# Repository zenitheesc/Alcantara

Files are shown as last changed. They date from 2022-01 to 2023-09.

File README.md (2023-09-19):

<h1 align="center" style="color:white; background-color:black">Alcantara</h1>
<h4 align="center"> Mobile Ground Station for stratospheric probe monitoring and rescue</h4>

<p align="center">
	<a href="http://zenith.eesc.usp.br/">
    
    </a>
    <a href="https://eesc.usp.br/">
    
    </a>
    <a href="https://github.com/zenitheesc/Alcantara_v.1.0/blob/experimental_realocate_components/LICENSE">
    
    </a>
    <a href="https://github.com/zenitheesc/Alcantara_v.1.0/issues">
    
    </a>
    <a href="https://github.com/zenitheesc/Alcantara_v.1.0/commits/experimental_realocate_components">
    
    </a>
    <a href="https://github.com/zenitheesc/Alcantara_v.1.0/graphs/contributors">
    
    </a>
    <a href="https://github.com/zenitheesc/Alcantara_v.1.0/commits/experimental_realocate_components">
    
    </a>
    <a href="https://github.com/zenitheesc/Alcantara_v.1.0/issues">
    
    </a>
    <a href="https://github.com/zenitheesc/Alcantara_v.1.0/pulls">
    
    </a>
</p>

<p align="center">
    <a href="#environment-and-tools">Environment and Tools</a> •
    <a href="#Block-Diagram">Block Diagram</a> •
    <a href="#Schematic">Schematic</a> • 
    <a href="#Board">Board</a> • 
    <a href="#BOM">BOM</a> • 
    <a href="#Use-Concept">Use Concept</a>
</p>

The Alcantara board functions as a ground station and data hub for the probe flights .

It is equipped with a EBYTE E22-900M30S 30dB module that carries the Semtech SX1262 transceiver, capable of LoRa, (G)FSK and OOK. The packets received from the probe can then be sent via WiFi, Bluetooth or Serially to a host computer or mobile phone.

The onboard GNSS module carries the NEO-M8N from u-blox, enabling it to be used as a tracking device.

## Environment and tools

This system was designed using KiCad 5.1.10.

## Block Diagram

<p align = "center">
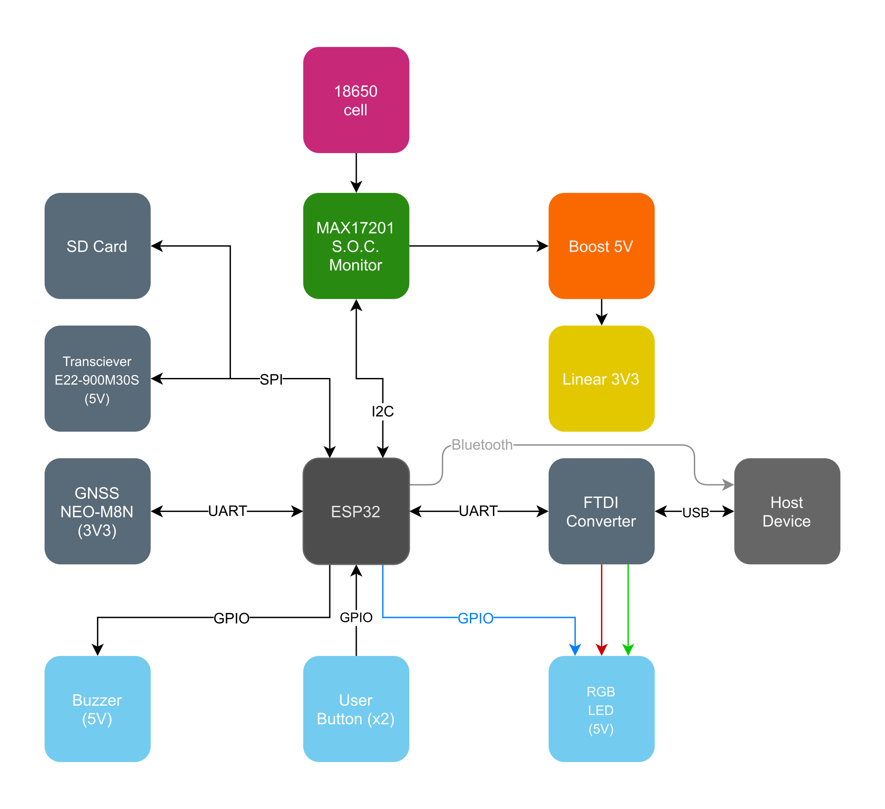
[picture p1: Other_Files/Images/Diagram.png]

</p>

## Schematic

The design was separated in hierarchical sheets to accommodate all components in an orderly way.

On the experimental_realocate_components sheet you can find the ESP32 WROOM Module, the SD Card module (connected via SPI), Boot and Reset button (with the Brownout prevention voltage supervisor), auto upload transistors and the external connector.

<p align = "center">
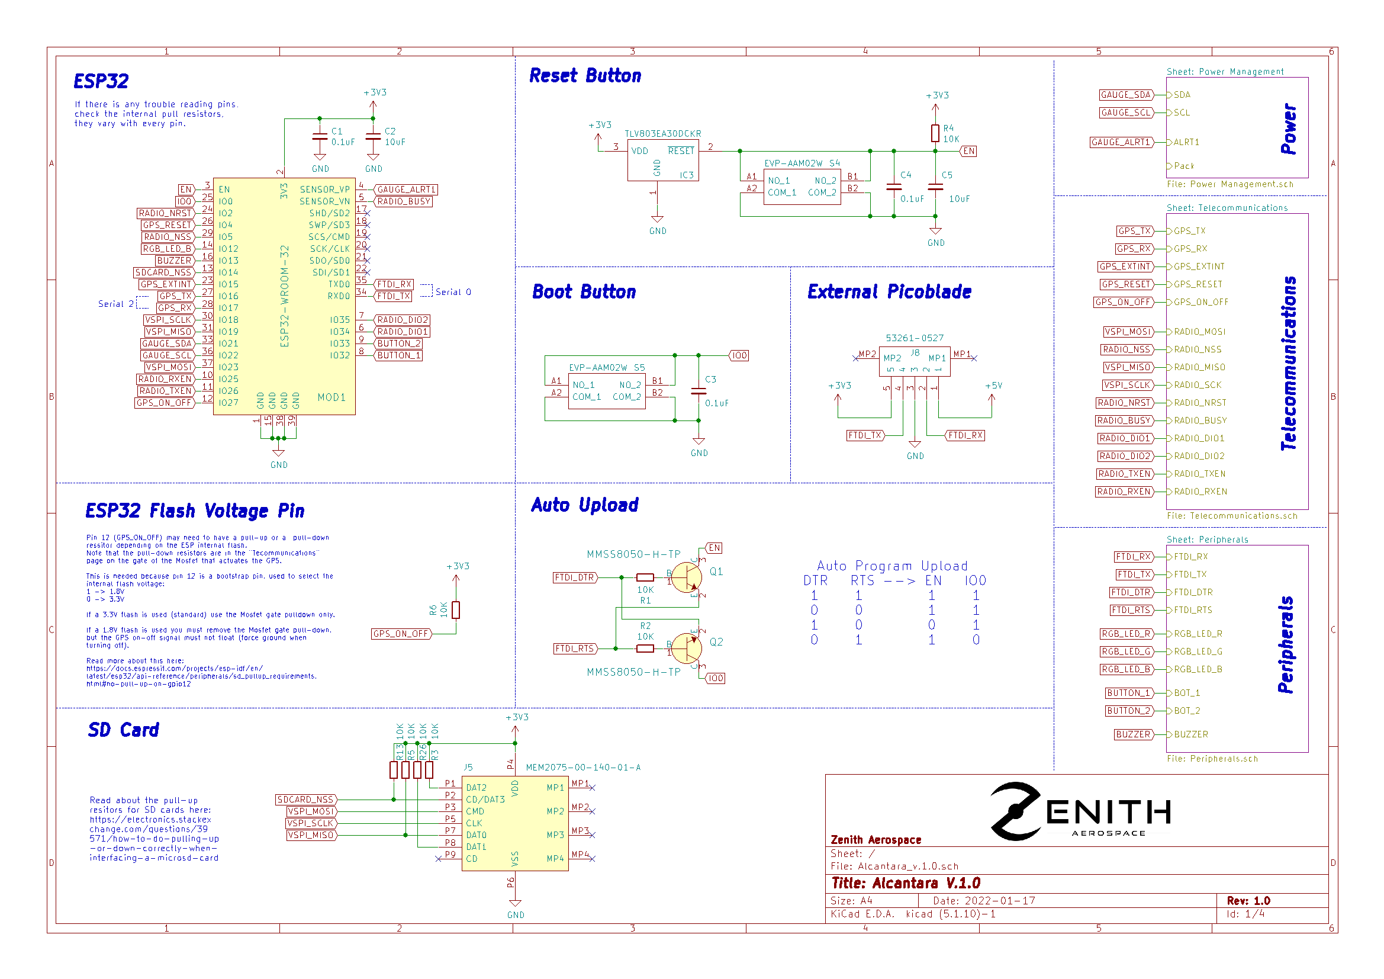
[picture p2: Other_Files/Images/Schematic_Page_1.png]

</p>

The second page contains the power section, with the TPS61092 Boost Converter (with another voltage supervisor for undervolting protection for the battery) for 5V, a 3.3V linear voltage regulator, the battery with a P channel mosfet for reverse voltage protection and a MAX17201G+T stand-alone fuel gauge for the 18650 battery voltage and current monitoring.

<p align = "center">
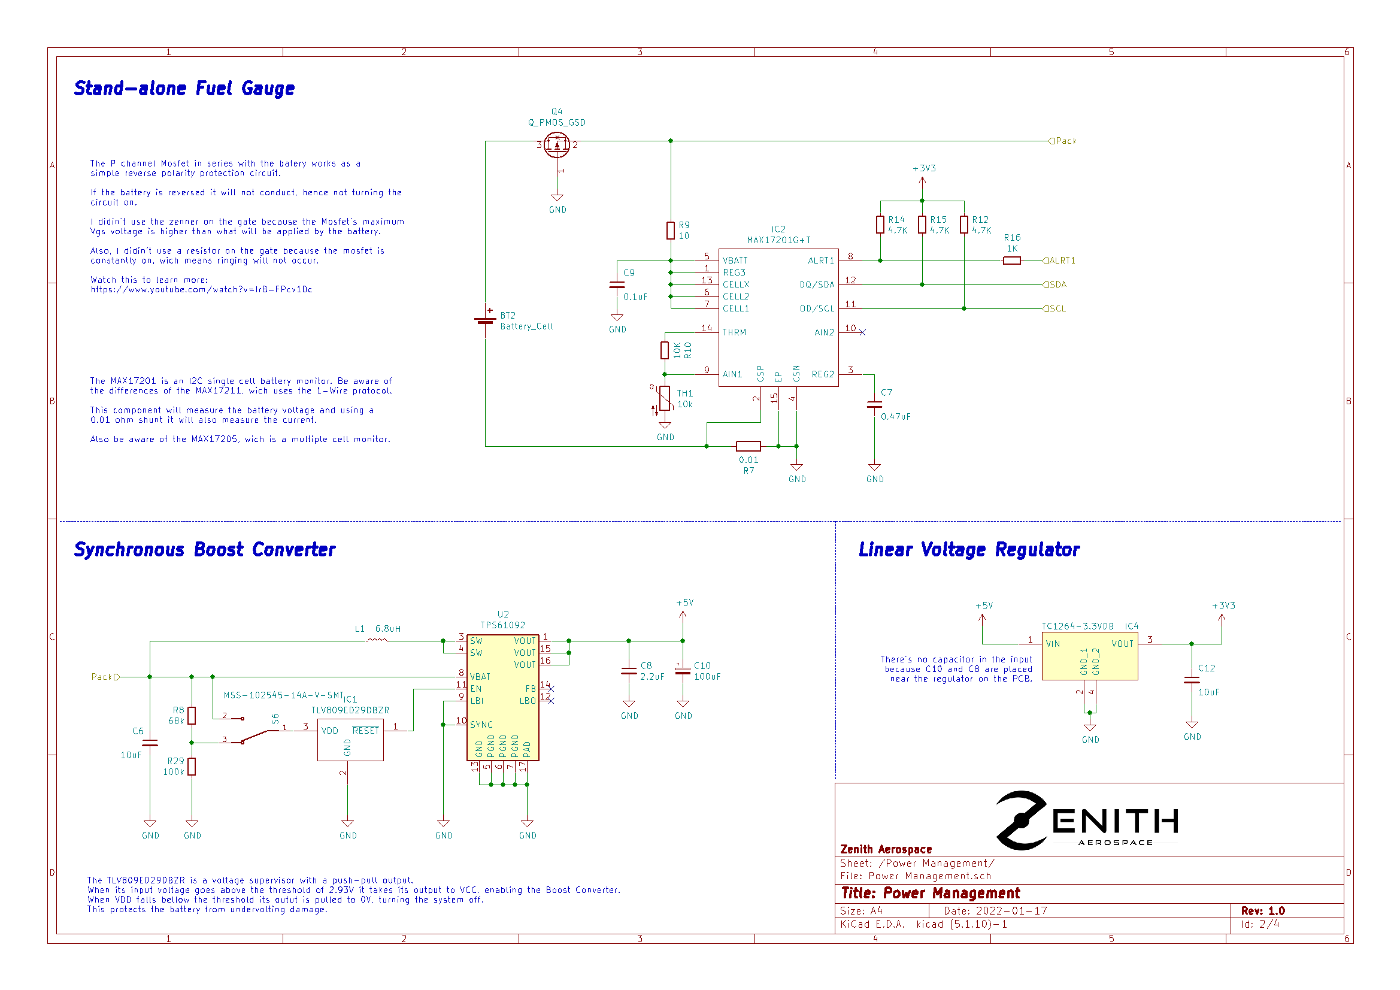
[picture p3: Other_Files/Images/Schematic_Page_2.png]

</p>

On the third page you find the Neo-M8N module from u-blox and the E22-900M30S module from EBYTE.

<p align = "center">
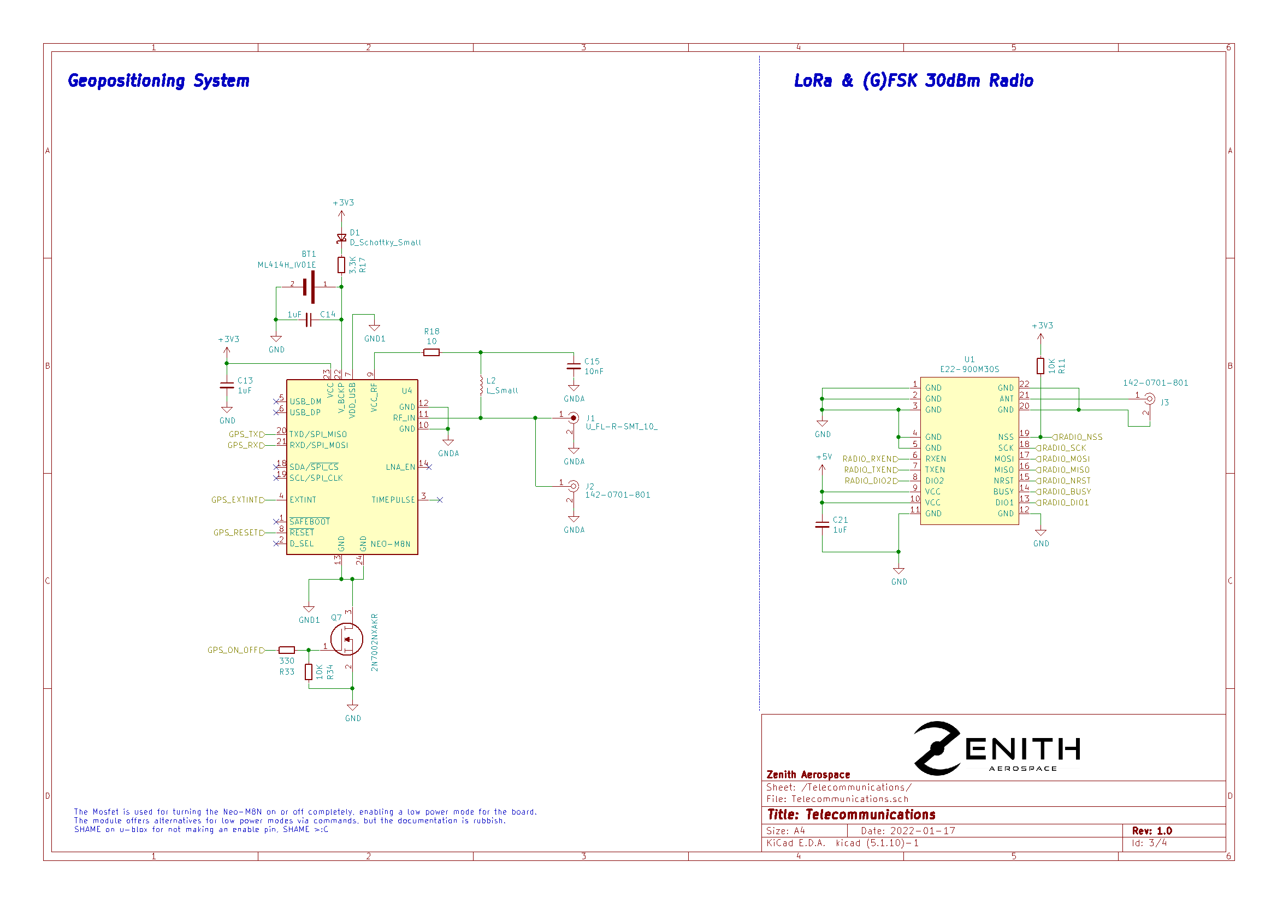
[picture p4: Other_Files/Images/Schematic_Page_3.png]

</p>

And the last page has the peripherals, the USB connector with its ESD protector, the RGB LED, the buzzer with its mosfet, the two user interface buttons and the USB to Serial Converter.

<p align = "center">
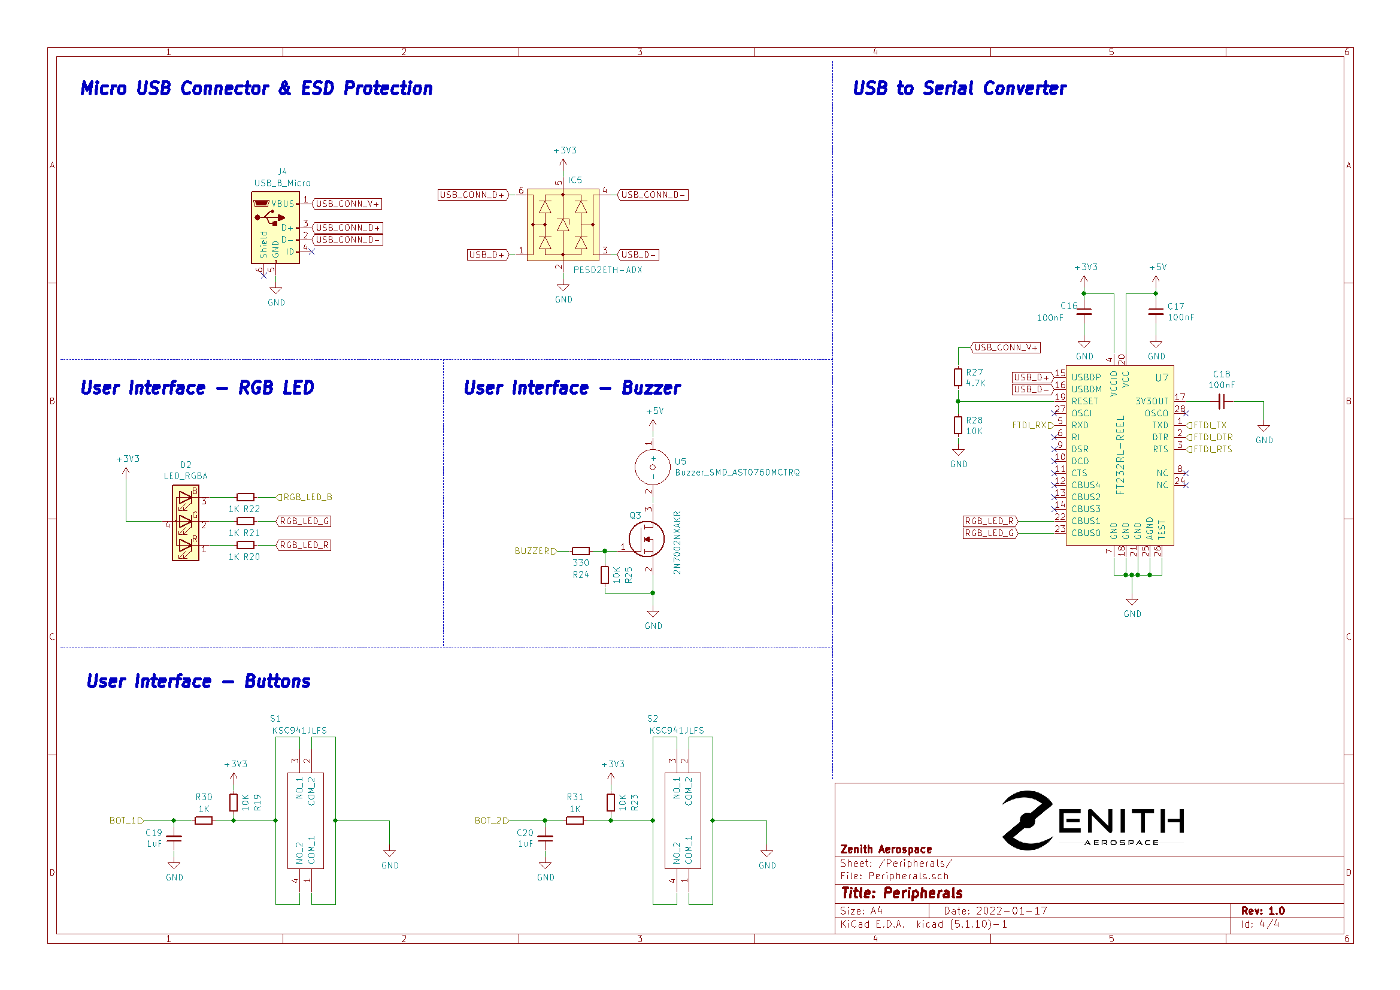
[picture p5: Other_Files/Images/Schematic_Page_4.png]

</p>

## Board

<p align = "center">
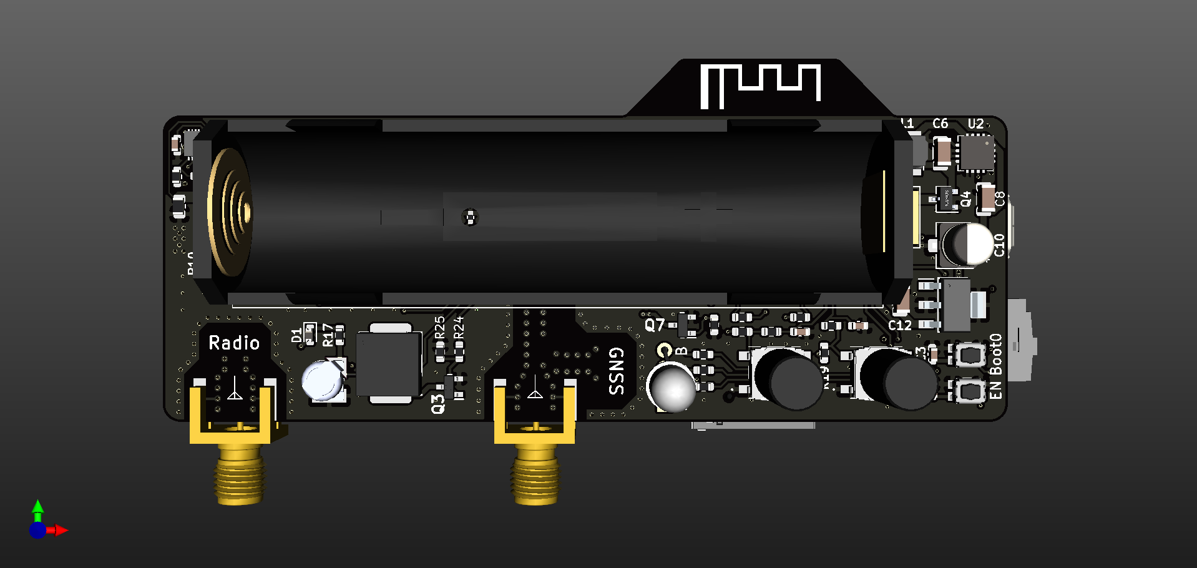
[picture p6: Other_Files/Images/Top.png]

</p>

<p align = "center">
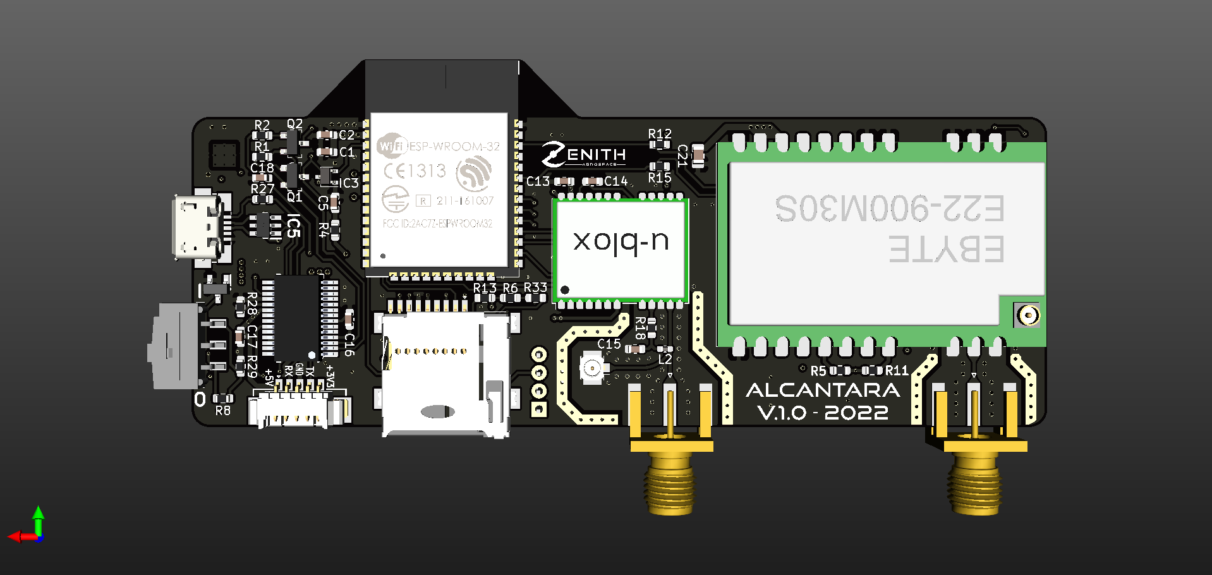
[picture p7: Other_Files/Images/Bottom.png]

</p>

<p align = "center">
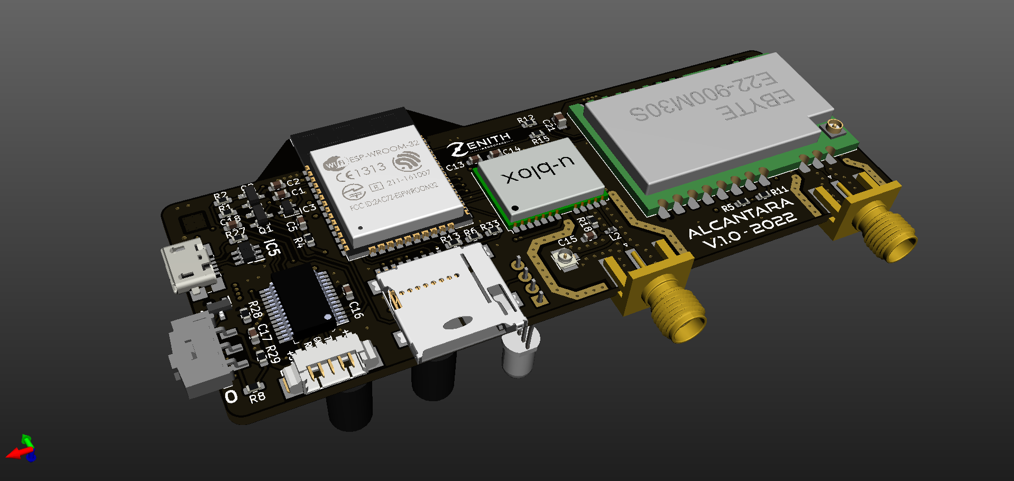
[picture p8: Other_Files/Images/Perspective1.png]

</p>

<p align = "center">
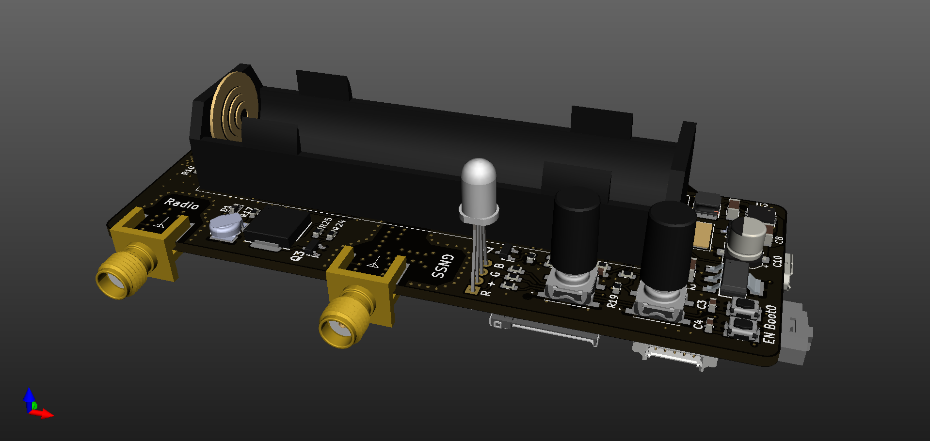
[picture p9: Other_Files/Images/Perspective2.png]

</p>

## Interactive BOM

https://htmlpreview.github.io/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

<!--
## Use concept

<p align = "center">
<img src="https://github.com/zenitheesc/Alcantara_v.1.0/blob/experimental_realocate_components/Other_Files/Images/PhoneConcept.png"/>
</p>

<p align = "center">
<img src="https://github.com/zenitheesc/Alcantara_v.1.0/blob/experimental_realocate_components/Other_Files/Images/BoxConcept.png"/>
</p>

---

<p align="center">
    <a href="http://zenith.eesc.usp.br">
    <img src="https://img.shields.io/badge/Check%20out-Zenith's Oficial Website-black?style=for-the-badge" />
    </a> 
    <a href="https://www.facebook.com/zenitheesc">
    <img src="https://img.shields.io/badge/Like%20us%20on-facebook-blue?style=for-the-badge"/>
    </a> 
    <a href="https://www.instagram.com/zenith_eesc/">
    <img src="https://img.shields.io/badge/Follow%20us%20on-Instagram-red?style=for-the-badge"/>
    </a>

</p>
<p align = "center">
<a href="zenith.eesc@gmail.com">zenith.eesc@gmail.com</a>
</p>
-->

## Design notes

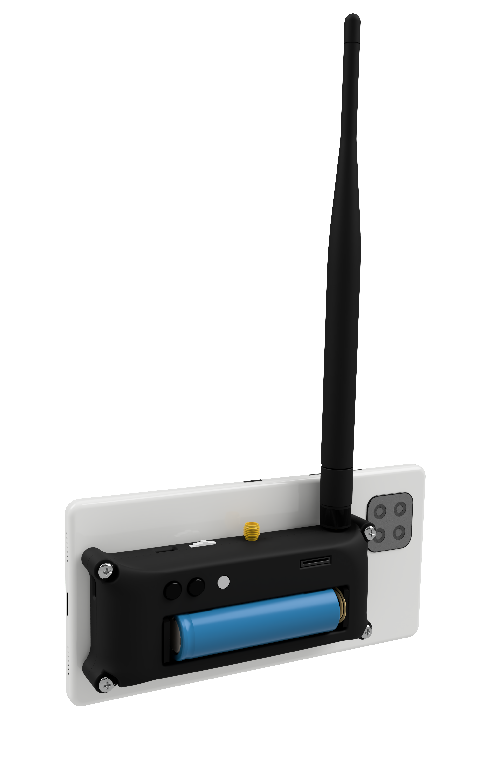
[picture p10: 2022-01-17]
docs/img/PhoneConcept.png

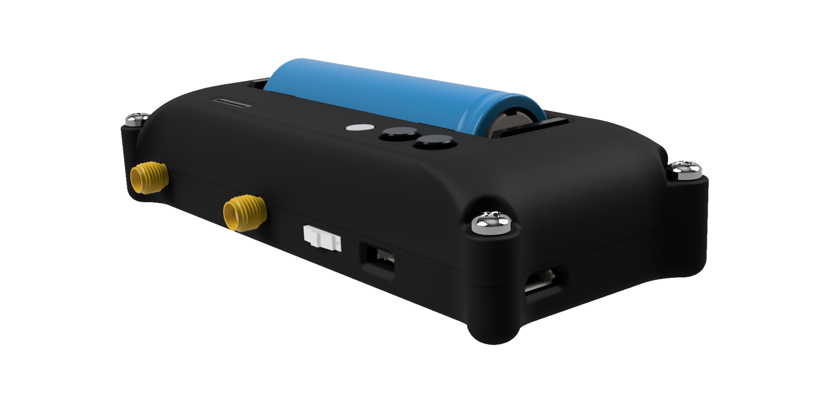
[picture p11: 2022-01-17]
docs/img/BoxConcept.png

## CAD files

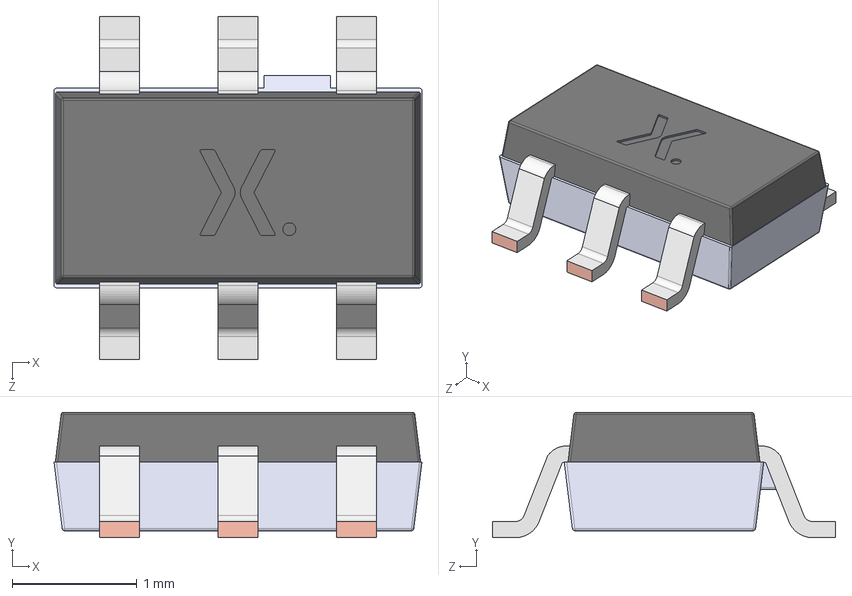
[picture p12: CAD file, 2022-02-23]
hardware/kicad/shapes3D/PESD2ETH-ADX.stp
2.95 x 1.01 x 2.75 mm
SOT457 Lower body
SOT457 Lead x 6
SOT457 Upper body

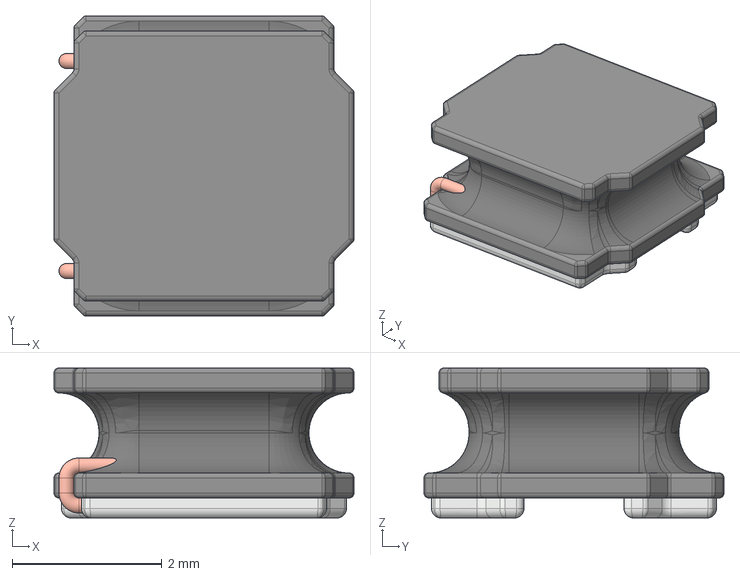
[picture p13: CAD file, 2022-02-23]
hardware/kicad/shapes3D/NR3015_4mm.step
4.00 x 4.00 x 2.00 mm

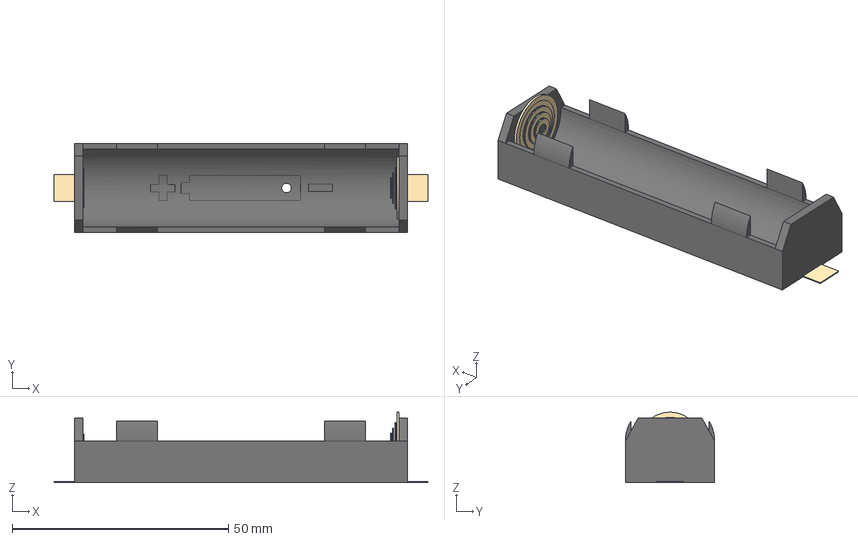
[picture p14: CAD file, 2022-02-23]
hardware/kicad/shapes3D/BatteryHolder_Keystone_1042_1x18650_With_Hole.step
86.4 x 20.6 x 16.3 mm

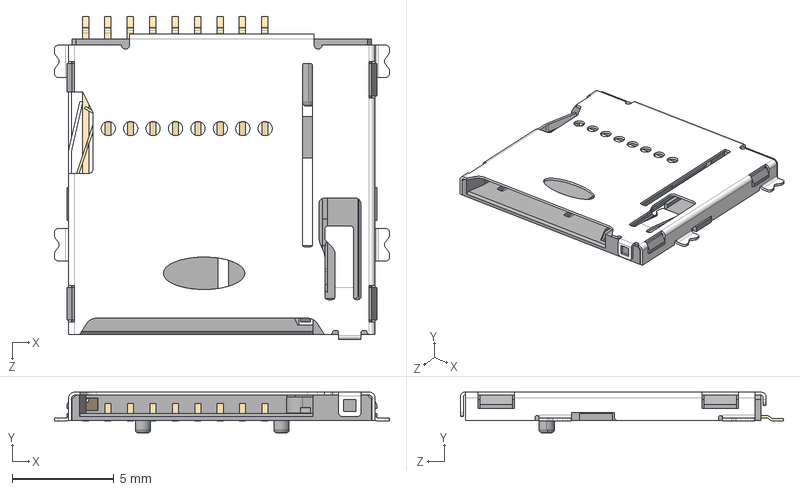
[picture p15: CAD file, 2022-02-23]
hardware/kicad/shapes3D/MEM2075-00-140-01-A.stp
16.4 x 2.00 x 15.9 mm

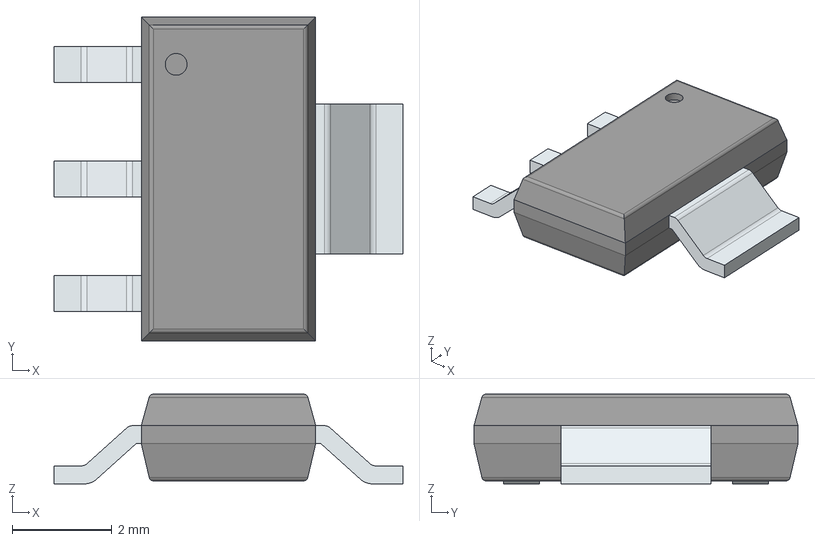
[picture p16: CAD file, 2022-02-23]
hardware/kicad/shapes3D/TC1264-3.3VDB.stp
7.00 x 6.50 x 1.80 mm
PinsArrayL
FilletPinR

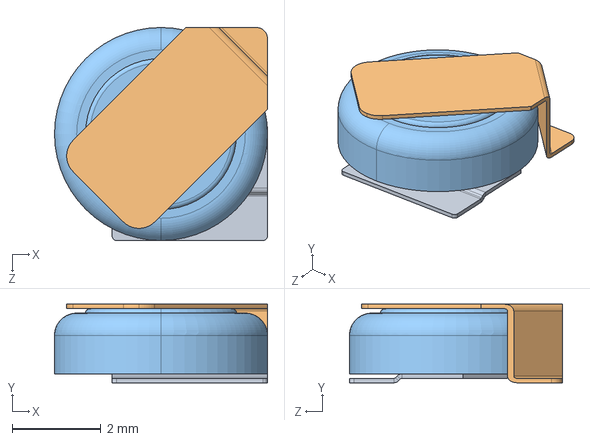
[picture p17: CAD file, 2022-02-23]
hardware/kicad/shapes3D/ML414H IV01E--3DModel-STEP-56544.step
4.80 x 1.77 x 4.80 mm

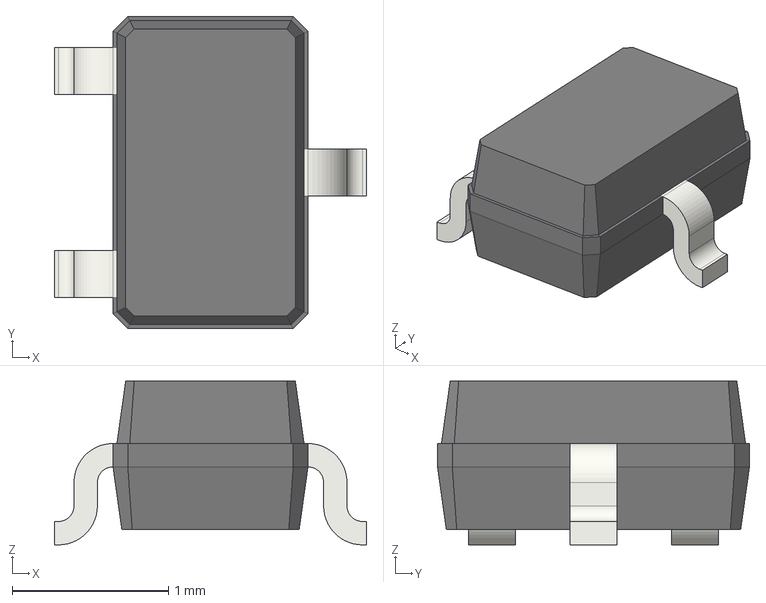
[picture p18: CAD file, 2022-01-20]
hardware/kicad/shapes3D/SOT-323_SC-70.step
2.00 x 2.00 x 1.05 mm

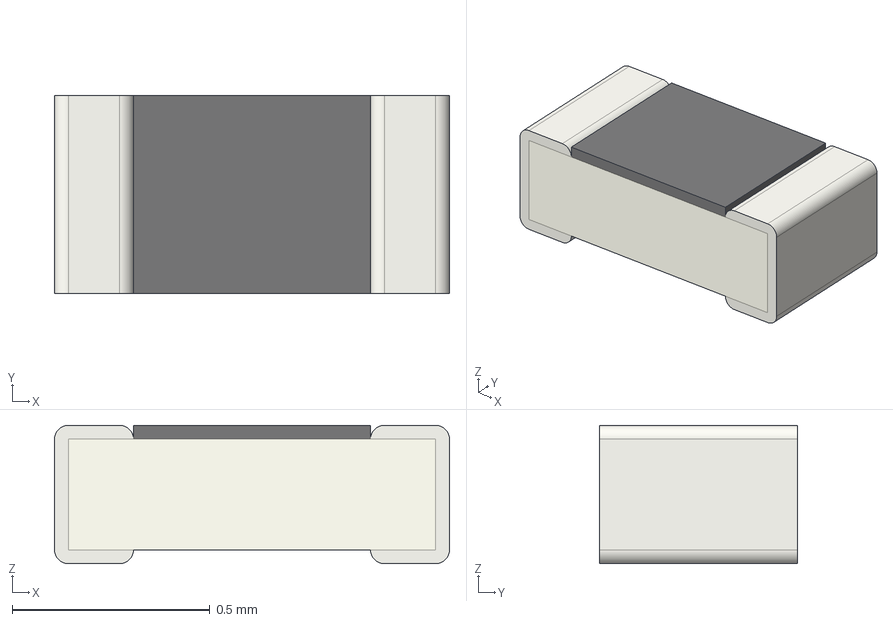
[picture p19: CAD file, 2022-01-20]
hardware/kicad/shapes3D/R_0402_1005Metric.step
1.00 x 0.5 x 0.35 mm

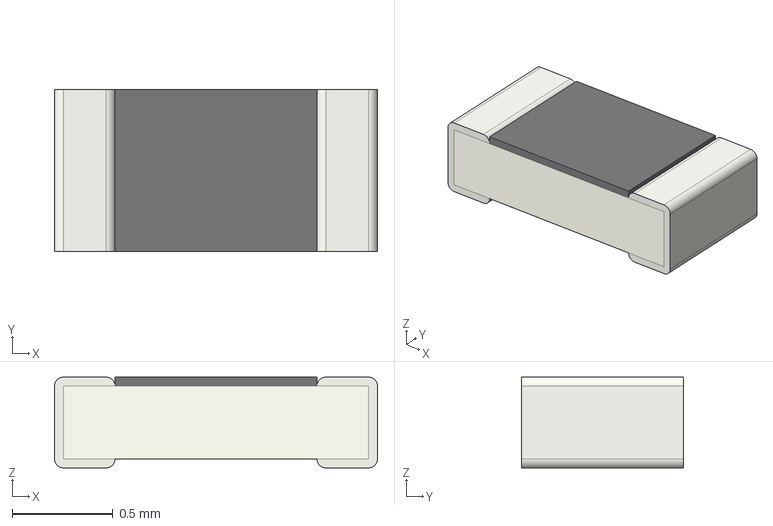
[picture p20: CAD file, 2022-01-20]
hardware/kicad/shapes3D/R_0603_1608Metric.step
1.60 x 0.8 x 0.45 mm

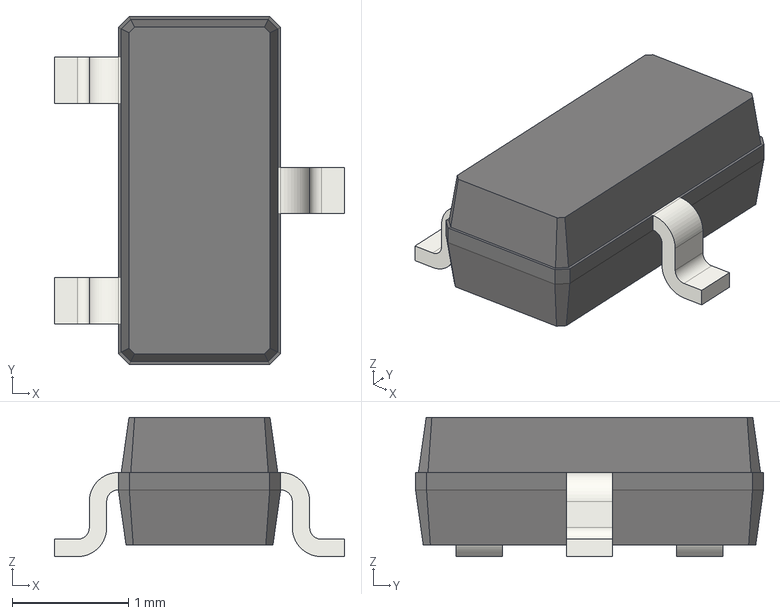
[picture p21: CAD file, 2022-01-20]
hardware/kicad/shapes3D/SOT-23.step
2.50 x 3.00 x 1.20 mm

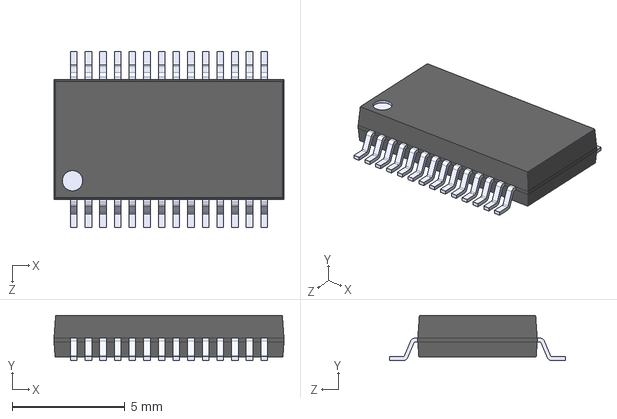
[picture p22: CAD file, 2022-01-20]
hardware/kicad/shapes3D/ssop28_model.step
10.2 x 2.00 x 7.80 mm
ssop28_pin x 28
ssop28_body

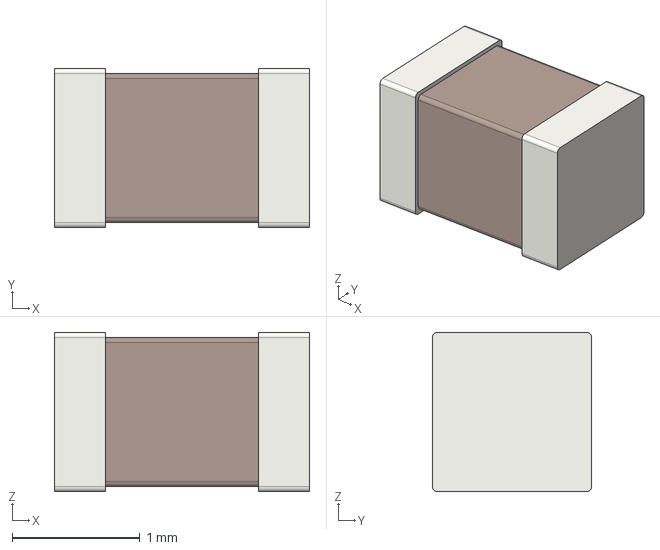
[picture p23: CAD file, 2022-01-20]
hardware/kicad/shapes3D/C_0805_2012Metric.step
2.00 x 1.25 x 1.25 mm

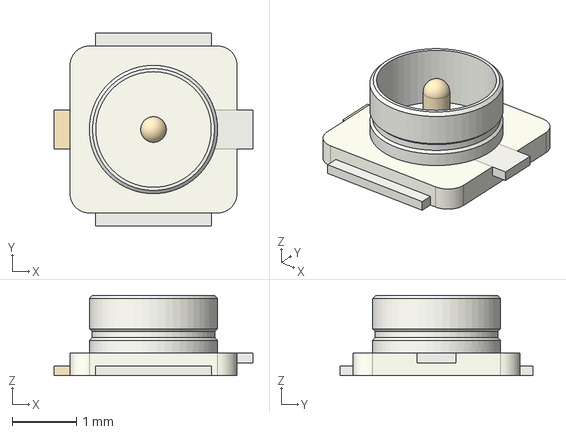
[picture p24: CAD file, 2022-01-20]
hardware/kicad/shapes3D/U.FL_Hirose_U.FL-R-SMT-1_Vertical.step
3.10 x 3.00 x 1.25 mm

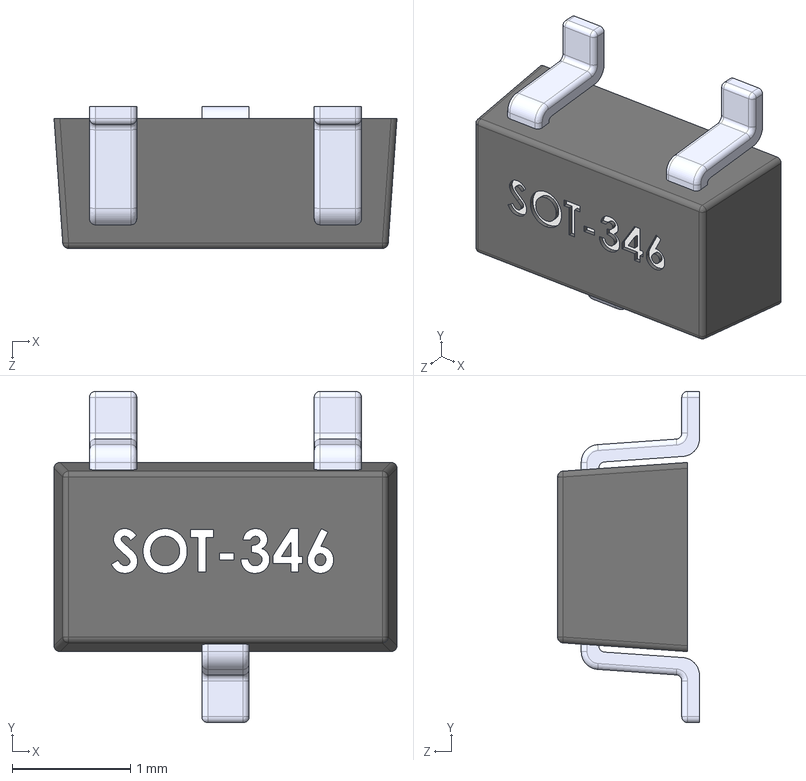
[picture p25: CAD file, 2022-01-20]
hardware/kicad/shapes3D/User Library-User Library-SOT-346T.step
2.90 x 2.80 x 1.20 mm
User Library-SOT-346T_27980_01
User Library-SOT-346T_27980_02
User Library-SOT-346T_27980_03
User Library-SOT-346T_27980_04

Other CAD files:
hardware/kicad/shapes3D/RGB_LED_Vertical_Zenith_Short v2.step
hardware/kicad/shapes3D/R_0805_2012Metric.step
hardware/kicad/shapes3D/Texas_S-PVQFN-N16_EP2.7x2.7mm.step
hardware/kicad/shapes3D/BTNKSC990 + Cap.step
hardware/kicad/shapes3D/2N7002NXAKR.stp
hardware/kicad/shapes3D/AST0760MCTRQ.step
hardware/kicad/shapes3D/Amphenol 132415.step
hardware/kicad/shapes3D/BatteryHolder_Keystone_1042_1x18650_No_Stubs.step
hardware/kicad/shapes3D/CP_Elec_5x5.3.step
hardware/kicad/shapes3D/CUI_DEVICES_MSS-102545-14A-V-SMT.step
hardware/kicad/shapes3D/C_0603_1608Metric.step
hardware/kicad/shapes3D/C_1206_3216Metric.step
hardware/kicad/shapes3D/D_0603_1608Metric.step
hardware/kicad/shapes3D/E22-900M30S v3.step
hardware/kicad/shapes3D/ESP32_Wroom.step
hardware/kicad/shapes3D/EVPAA.step
hardware/kicad/shapes3D/L_0402_1005Metric.step
hardware/kicad/shapes3D/MAX17201G+T.stp
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

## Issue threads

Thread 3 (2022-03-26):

Bring-Up com Arduino IDE

leocelente, 2022-03-26:
Criar uma branch com uma estrutura de pastas para o desenvolvimento do projeto da Arduino IDE
```shell
git checkout -b firmware
```
Folder structure:
```
Alcantara/
    | - ...
    | - firmware/
        | - alcantara/
            | - acantara.ino
```
A ideia é construir aos poucos o firmware. O primeiro é o hello world, que envolve:
  - [x]   Instalar a Arduino IDE
  - [x]   Adicionar o ESP32 como Board
  - [x]   Criar o projeto na pasta correta
  - [x]   "Hello World" via Serial
  - [x]   Compilar
  - [x]   Executar em uma das ESP32 da salinha

Em teoria é tudo bem rapidinho :)
Terminando essa parte, tem outro issue com a tarefa mais relacionada a funcionalidade da Alcantara.

Closed 2023-06-26.

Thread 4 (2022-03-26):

Data Handling

leocelente, 2022-03-26:
O objetivo da Alcantara é processar e repassar os pacotes vindo do rádio para interfaces como UART e BLE. Então a operação
mais importante é converter pacotes do rádio em _strings csv_.  Mas ela se comporta de diferentes maneiras dependendo do contexto. Ela pode estar em uma de duas redes (OBSAT ou Zenith). Dependendo de qual das duas, ela irá processar tipos de pacotes diferentes.

 - Caso rede OBSAT:
     - Pacote: OBSAT - Contém dados dos competidores
 - Caso rede Zenith:
     - Pacote: Zenith_Full - Contém o máximo de dados da sonda
     - Pacote: Zenith_Reduced - Contém os dados mínimos da sonda

**A entrada do sistema será um array de bytes vindo do rádio**. dentro desse array o primeiro byte indica o *tipo* de pacote. Os pacotes podem ser:
1. OBSAT:
2. Zenith_Reduced:
3. Zenith_Full:

Então será necessário uso de `unions` para converter os dados entre um conjunto de bytes e uma `struct`. Com os dados extraídos, é
bom que sejam feitos checks simples para evitar propagar dados obviamente incorretos. Finalmente as informações da `struct` devem ser convertidos na _string_  adequada.

 - Lembre de organizar o código de forma clara.
 - Lembre commitar com mensagens claras referenciando este issue
 - Caso tenha dúvidas pode mandar neste issue

Pode supor as structs como:
```c

typedef struct {
	uint8_t day, month, year;
	uint8_t second, minute, hour;
	float latitude, longitude, altitude;
	float speed_x, speed_y, speed_z;
} gps_event_t;

typedef struct {
	float latitude, longitude, altitude;
	float preassure_primary;
	float temp_1, temp_2, temp_3;
	float v_1, v_2, v_3;
	float i_1, i_2, i_3;
	float batt_charge;
	uint8_t seconds, minutes, hours;
	uint8_t packet_id;
} radio_full_packet_values_t;

typedef struct {
	float latitude, longitude, altitude;
	float preassure_primary;
	float batt_charge;
	uint8_t seconds, minutes, hours;
	uint8_t packet_id;
} radio_reduced_packet_values_t;

typedef uint8_t obc_blob_t[92];

typedef struct {
	uint8_t id;
	obc_blob_t data;
} radio_obsat_packet_values_t;
```

leocelente, 2022-06-10:
- Colocar o sistema de escolher a função de parse (via ponteiro de função)
     - Adicionar membros no config state
 - Contador de pacotes
 - Pegar structs de packet do CDH.h
 - Fazer `last_packet` struct com todos os tipos pacotes
 - Integração com SDCard e UART
 -

Closed 2023-06-26.

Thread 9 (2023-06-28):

RTOS

FernandoCZanchetta, 2023-06-28:
Como a Alcântara estará lidando com várias tarefas acontecendo simultaneamente, como receber dados do rádio, processar esses dados recebidos, enviar os dados via UART, salvar os dados no cartão SD, piscar o LED indicando o modo de operação atual, entre outras, um RTOS é uma implementação interessante para gerenciar tais tarefas e quais delas devem acontecer dada sua prioridade para o funcionamento do dispositivo.

Sendo assim, utilizando a biblioteca ```FreeRTOS.h```, serão implementadas três tasks principais:

- Uma task para piscar o LED, indicando para o usuário qual é o modo atual de operação, com prioridade baixa;
- Uma task para receber os dados do rádio e colocá-los numa fila;
- Uma task para retirar os dados da fila e parseá-los, convertendo os bytes recebidos no rádio em cada um de seus componentes e tipos, e enviando-os via UART e gravando-os no cartão SD.

Closed 2023-10-19.

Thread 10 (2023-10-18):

BLE

FernandoCZanchetta, 2023-10-18:
Para facilitar a leitura dos dados tratados pela Alcântara, será utilizado o Bluetooth Low Energy (BLE) para transmitir esses dados para um dispositivo próximo, assim, será possível ler os dados a partir do terminal bluetooth de um dispositivo celular, por exemplo. Isto será importante para ter acesso aos dados de localização da sonda, ou outros dados de interesse.

Sendo assim, utilizando as bibliotecas BLEDevice.h, BLEUtils.h e BLEServer.h, será implementado um servidor BLE, pelo qual serão passados os pacotes recebidos para visualização no dispositivo que se conectar à Alcântara.

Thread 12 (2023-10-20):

Bluetooth Serial

FernandoCZanchetta, 2023-10-20:
Para facilitar o uso do Bluetooth, inicialmente, será utilizado o Bluetooth em seu modo normal, em vez do BLE, que possui maior economia de energia. Sendo assim, em momentos futuros deve-se buscar a implementação do BLE ou caso seja constatada a viabilidade energética do Bluetooth, sem drenar muita energia ou prejudicar outras funções da placa, manter-se a implementação atual.

Portanto, utilizando a biblioteca BluetoothSerial.h, será implementado um dispositivo BT-Slave, pelo qual serão passados os pacotes recebidos para visualização no dispositivo que se conectar à Alcântara.

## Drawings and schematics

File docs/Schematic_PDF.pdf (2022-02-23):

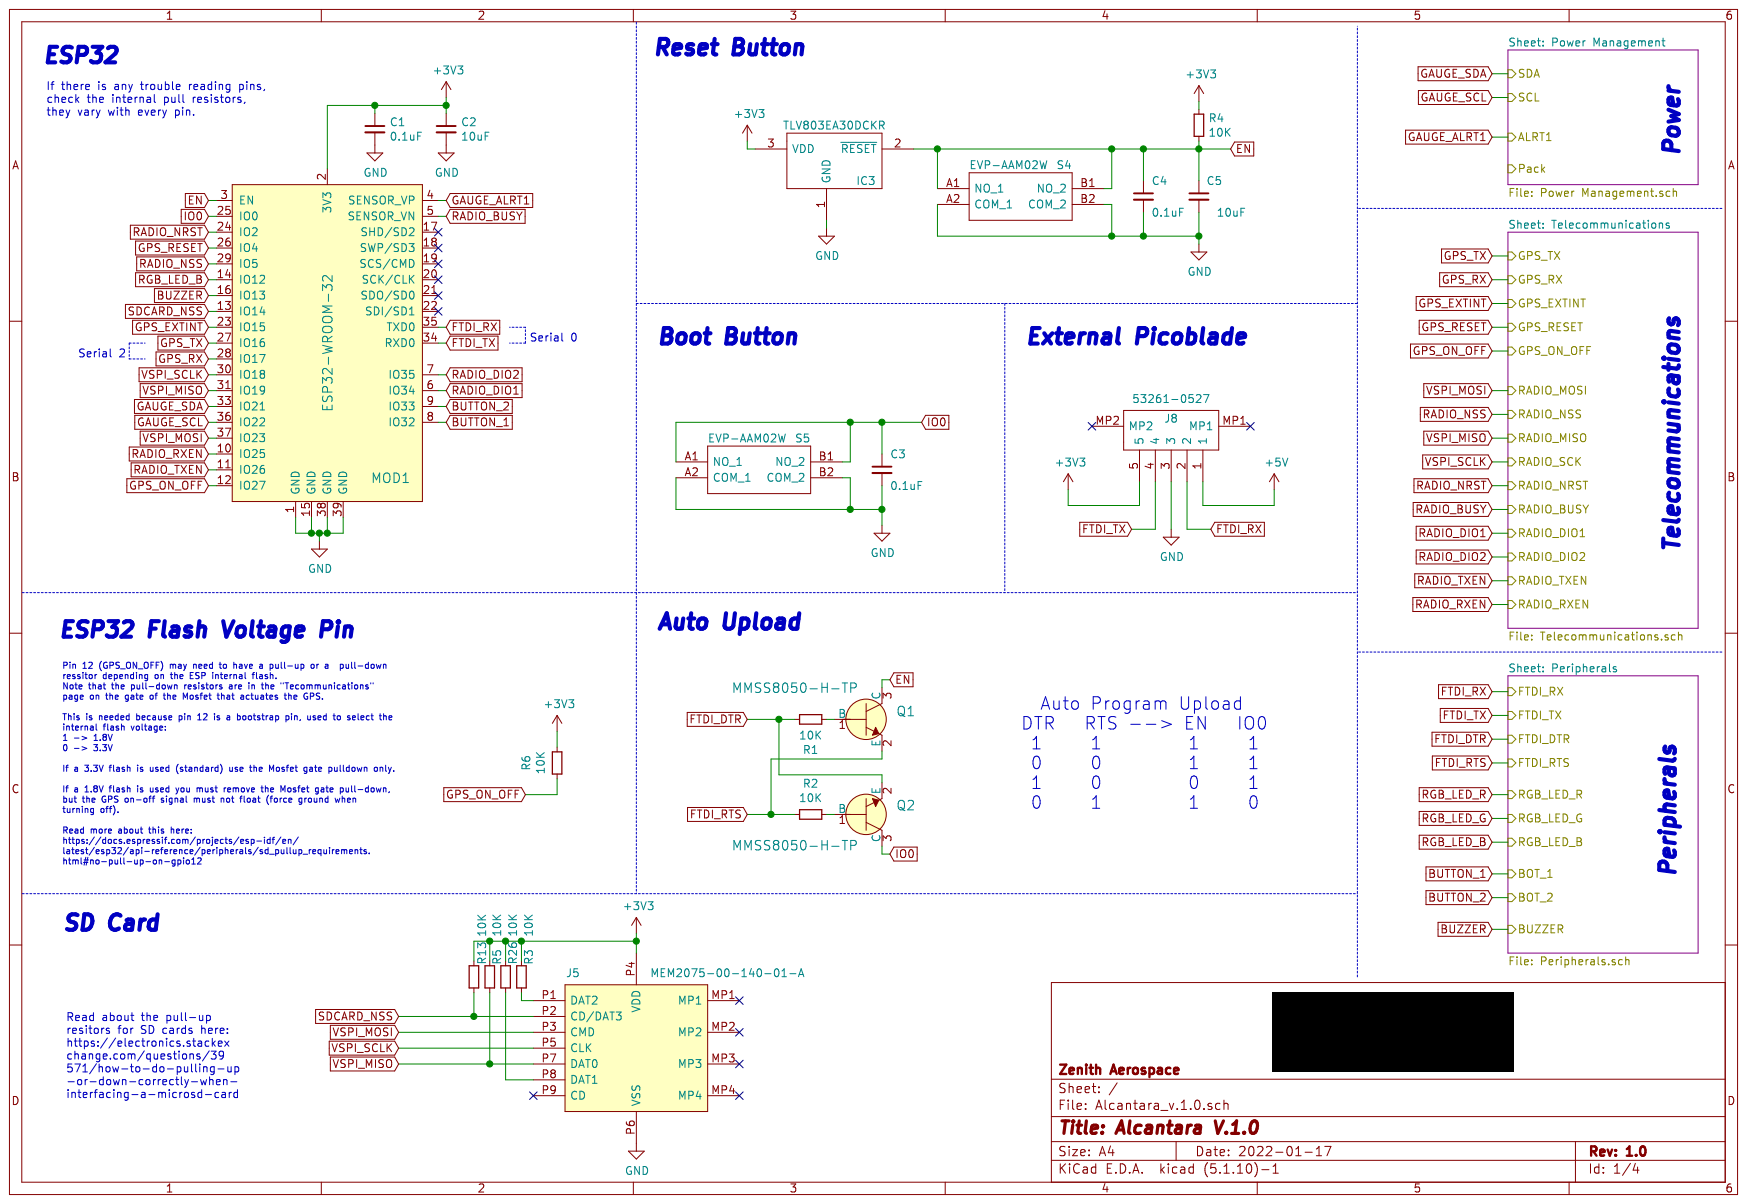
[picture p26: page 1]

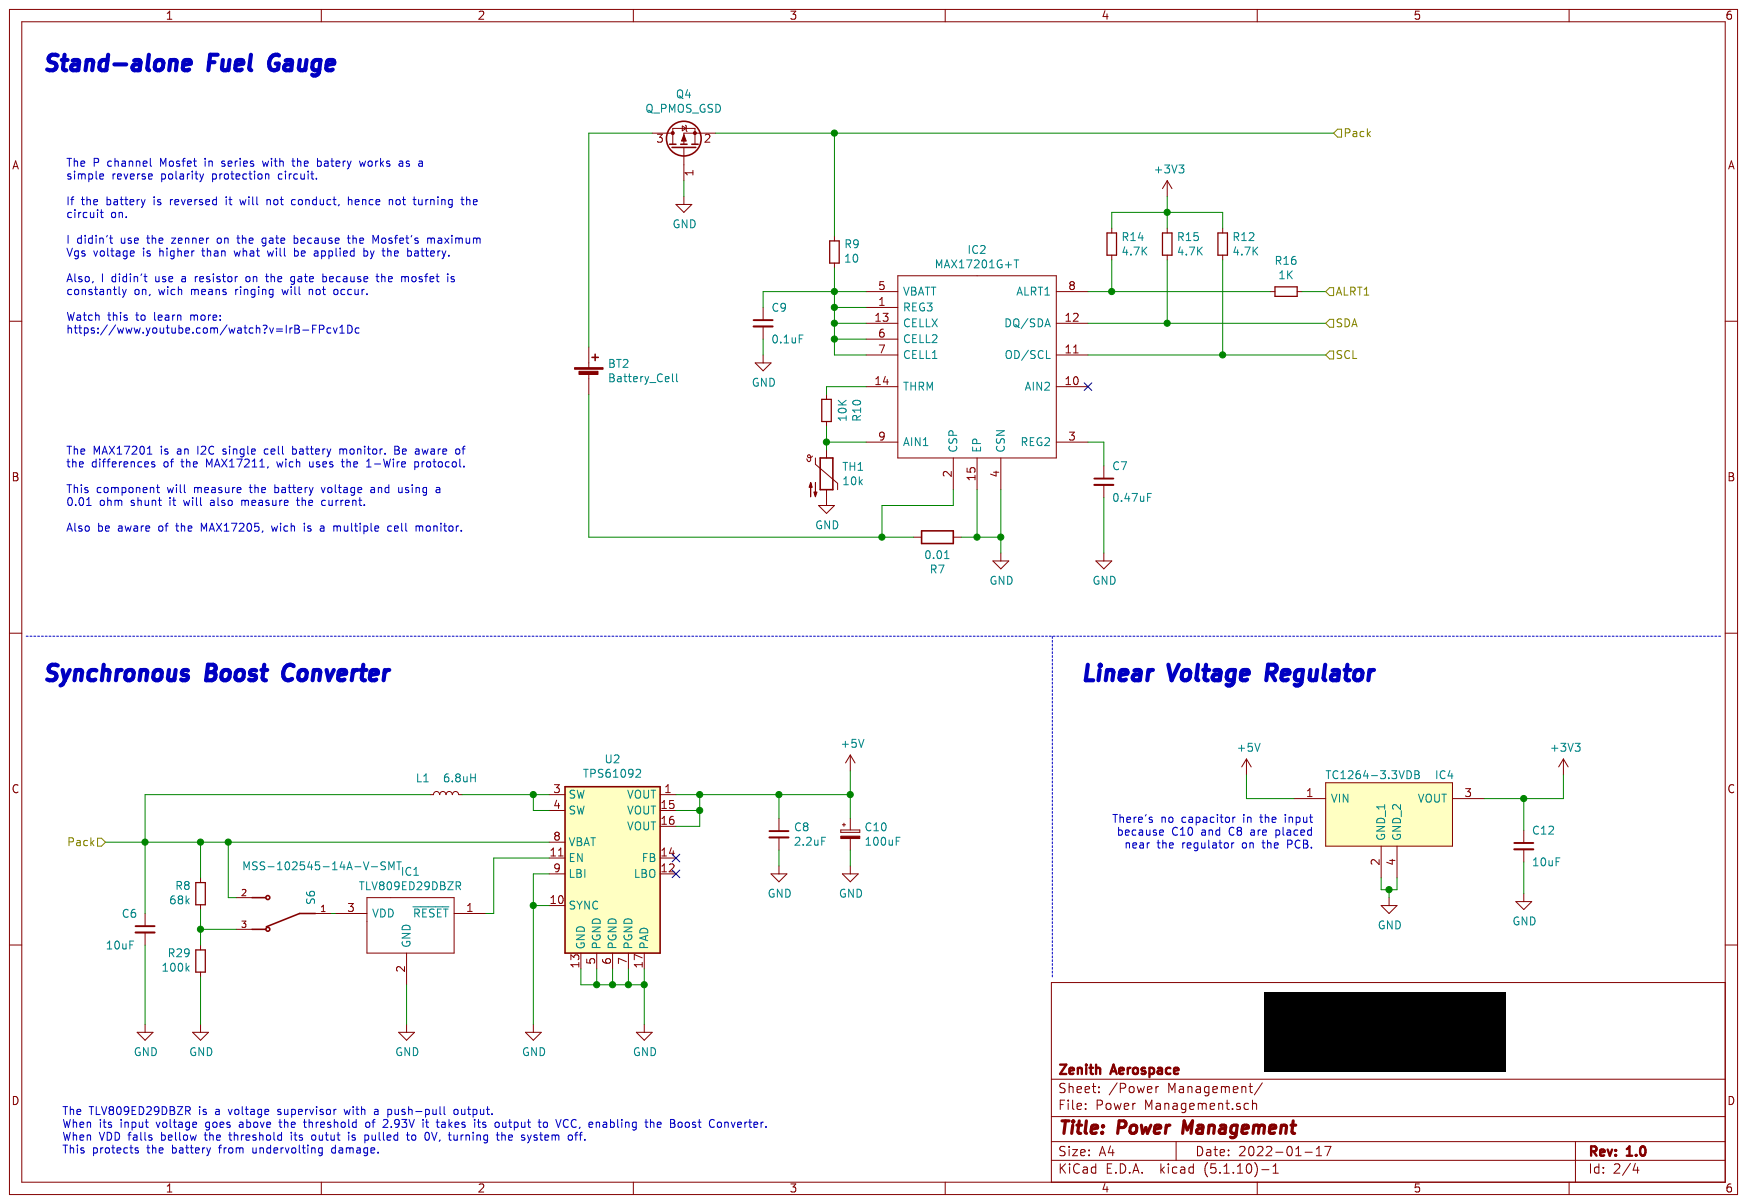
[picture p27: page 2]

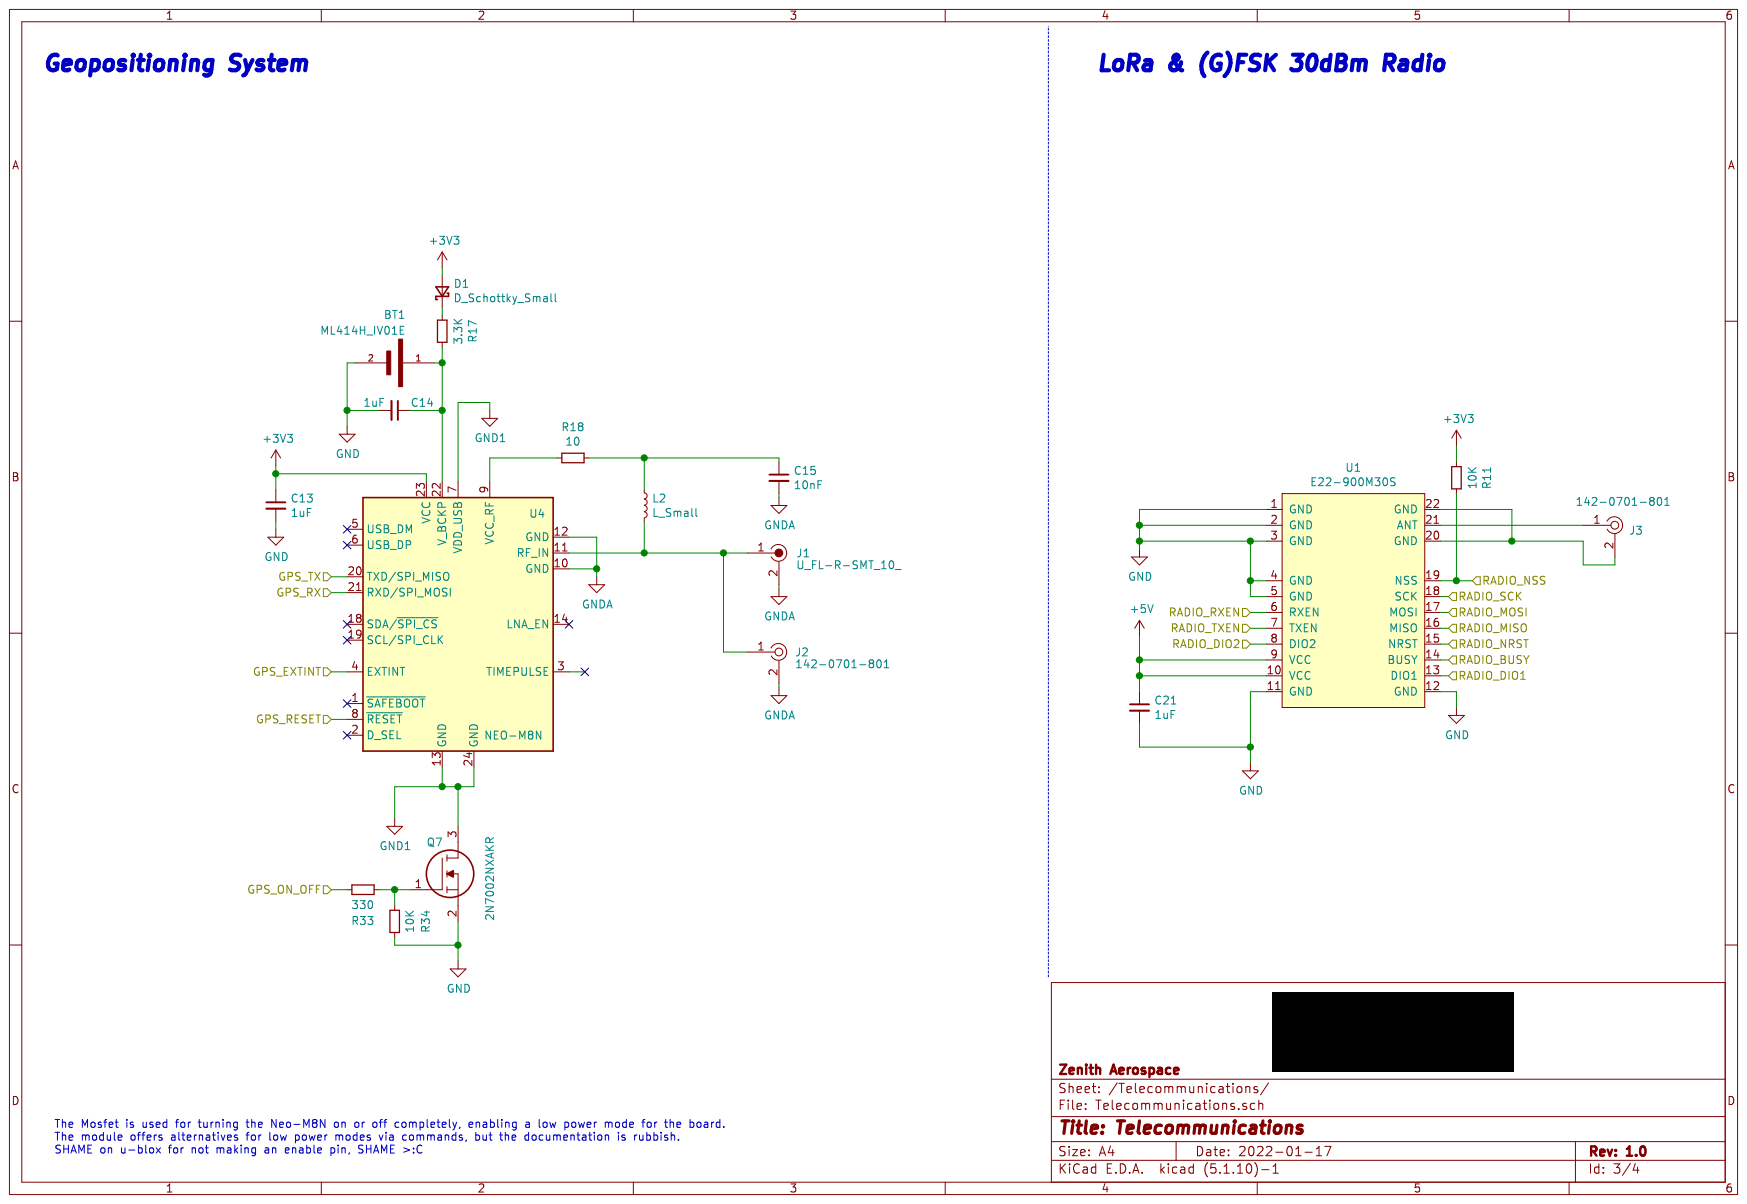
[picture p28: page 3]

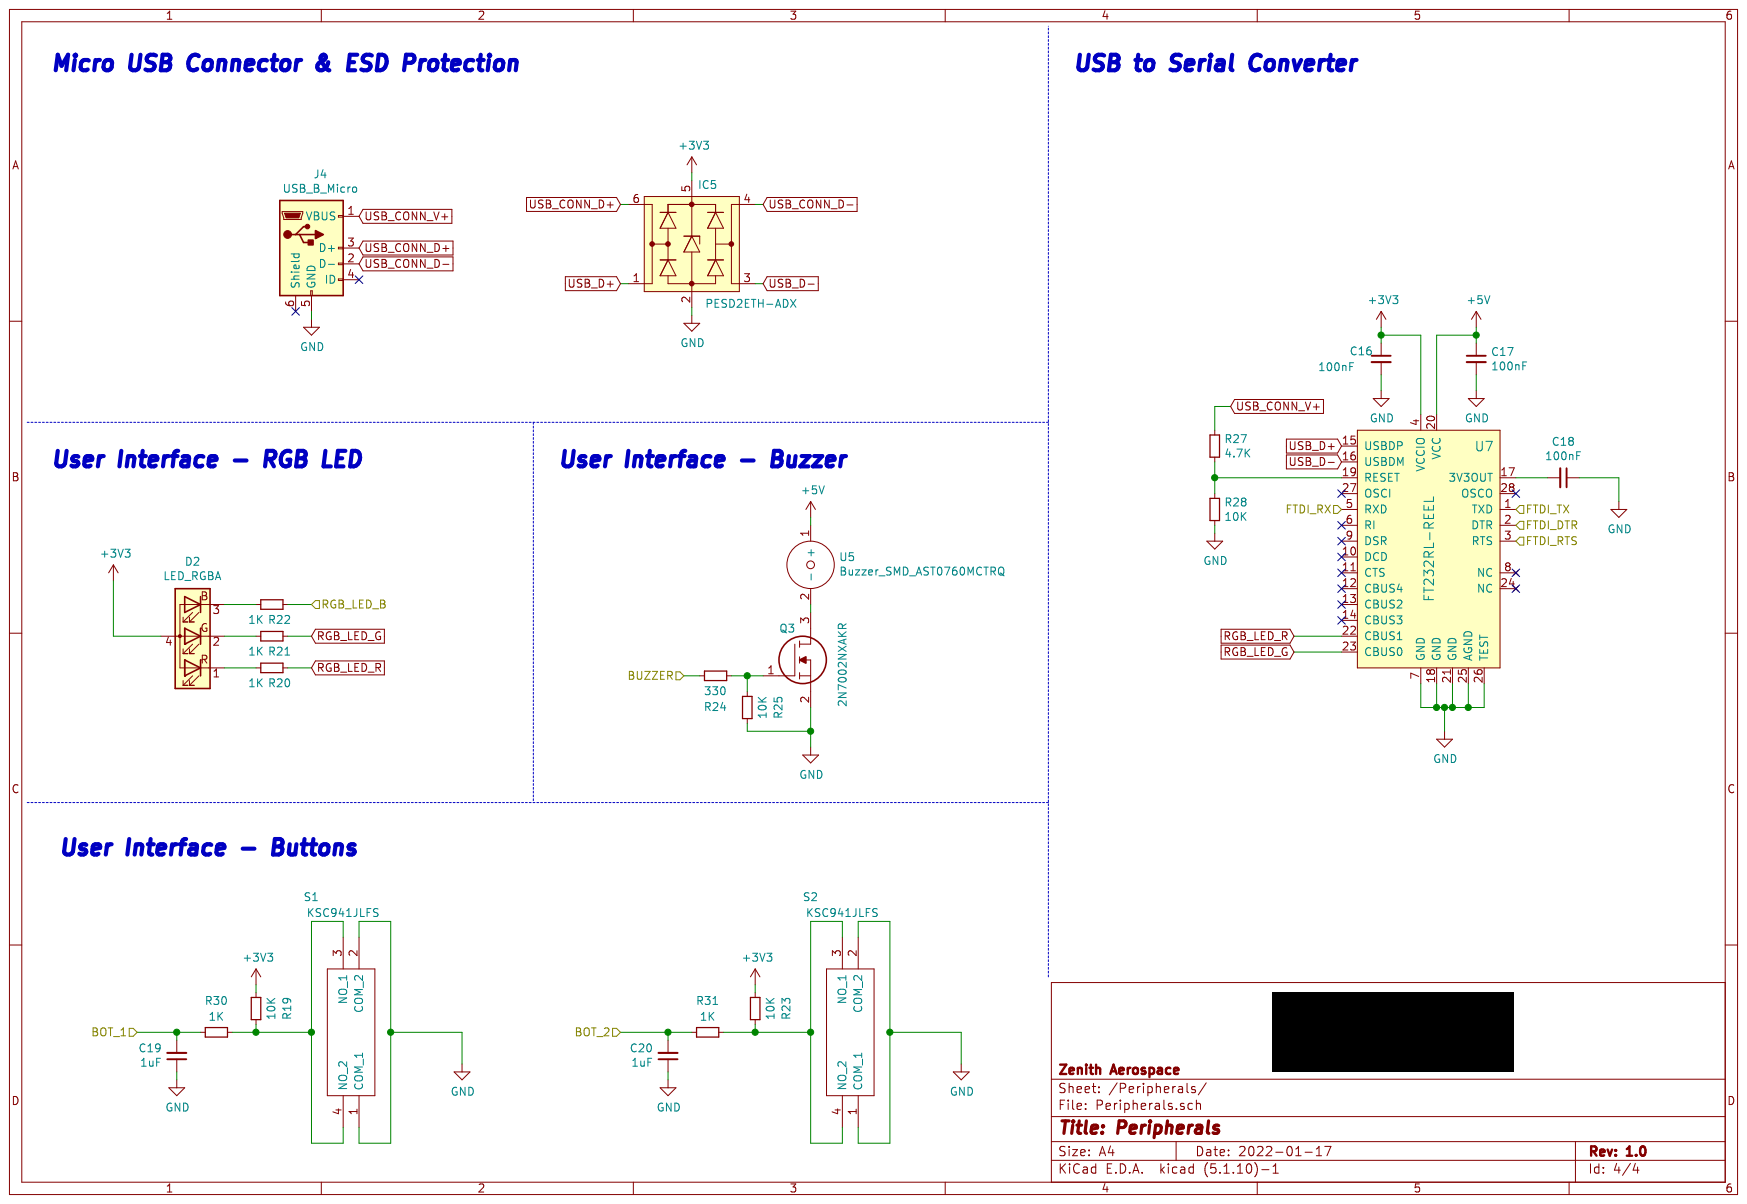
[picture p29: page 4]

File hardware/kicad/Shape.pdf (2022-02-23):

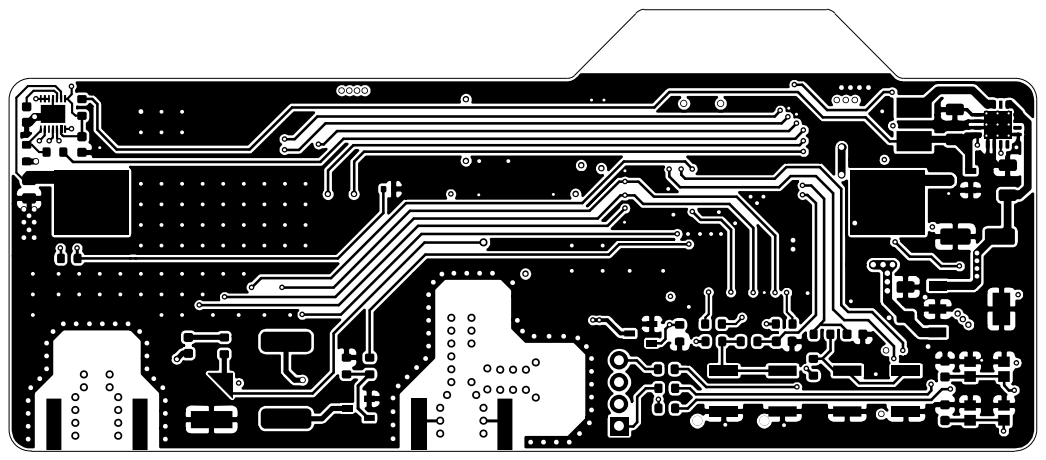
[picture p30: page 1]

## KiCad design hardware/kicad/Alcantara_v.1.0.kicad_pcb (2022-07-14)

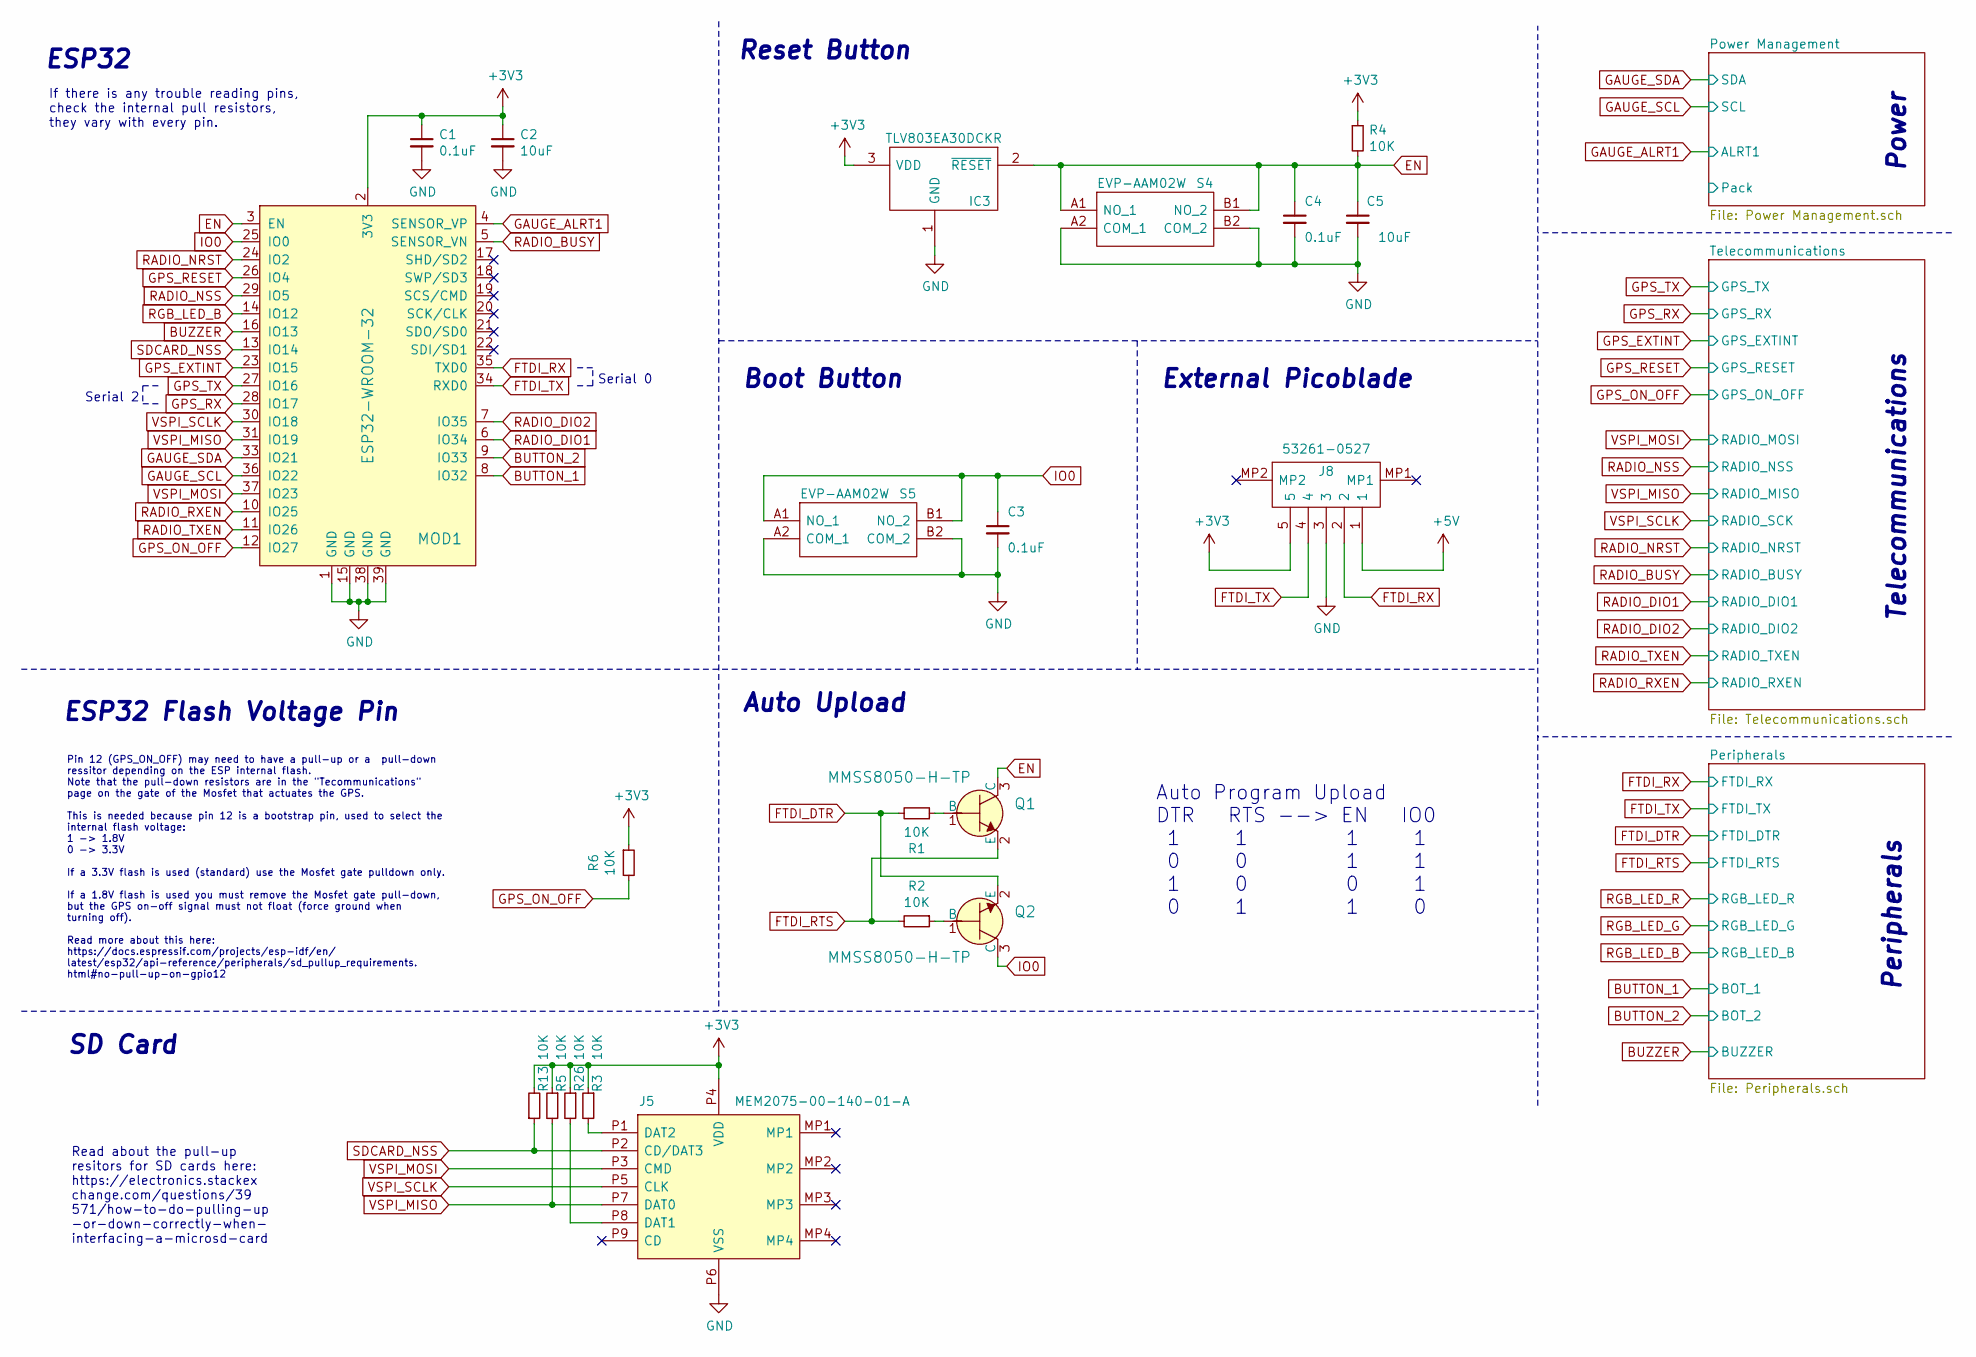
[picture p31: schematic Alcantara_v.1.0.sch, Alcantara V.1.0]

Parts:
C1, C3, C4: 0.1uF; C_0603_1608Metric
C2, C5: 10uF; C_0603_1608Metric
IC3: TLV803EA30DCKR; SOT-323_SC-70; Mouser Part Number 595-TLV803EA30DCKR
J5: MEM2075-00-140-01-A; MEM20750014001A; Mouser Part Number 640-MEM20750014001A
J8: 53261-0527; 532610527; Mouser Part Number 538-53261-0527
MOD1: ESP32-WROOM-32; ESP32-WROOM-32D; MPN ESP32-WROOM-32; Digi-Key_PN 1904-1010-1-ND
Q1, Q2: MMSS8050-H-TP; SOT-23-3; MPN MMSS8050-H-TP; Digi-Key_PN MMSS8050-H-TPMSCT-ND
R1, R2, R3, R4, R5, R6, R13, R26: 10K; R_0603_1608Metric
S4, S5: EVP-AAM02W; EVPAAM02W; Mouser Part Number 667-EVP-AAM02W

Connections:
+3V3: C1.1, C2.1, IC3.3 (VDD), J5.P4 (VDD), J8.5, MOD1.2 (3V3), R3.1, R4.1, R5.1, R6.1, R13.2, R26.1; also elsewhere on the board
+5V: J8.1; also elsewhere on the board
BUTTON_1: MOD1.8 (IO32); also elsewhere on the board
BUTTON_2: MOD1.9 (IO33); also elsewhere on the board
BUZZER: MOD1.16 (IO13); also elsewhere on the board
EN: C4.1, C5.1, IC3.2 (~RESET), MOD1.3 (EN), Q1.3 (C), R4.2, S4.A1 (NO_1), S4.B1 (NO_2)
FTDI_DTR: Q2.2 (E), R1.2; also elsewhere on the board
FTDI_RTS: Q1.2 (E), R2.2; also elsewhere on the board
FTDI_RX: J8.2, MOD1.35 (TXD0); also elsewhere on the board
FTDI_TX: J8.4, MOD1.34 (RXD0); also elsewhere on the board
GAUGE_ALRT1: MOD1.4 (SENSOR_VP); also elsewhere on the board
GAUGE_SCL: MOD1.36 (IO22); also elsewhere on the board
GAUGE_SDA: MOD1.33 (IO21); also elsewhere on the board
GND: C1.2, C2.2, C3.2, C4.2, C5.2, IC3.1 (GND), J5.P6 (VSS), J8.3, MOD1.1 (GND), MOD1.15 (GND), MOD1.38 (GND), MOD1.39 (GND), S4.A2 (COM_1), S4.B2 (COM_2), S5.A2 (COM_1), S5.B2 (COM_2); also elsewhere on the board
GPS_EXTINT: MOD1.23 (IO15); also elsewhere on the board
GPS_ON_OFF: MOD1.12 (IO27), R6.2; also elsewhere on the board
GPS_RESET: MOD1.26 (IO4); also elsewhere on the board
GPS_RX: MOD1.28 (IO17); also elsewhere on the board
GPS_TX: MOD1.27 (IO16); also elsewhere on the board
IO0: C3.1, MOD1.25 (IO0), Q2.3 (C), S5.A1 (NO_1), S5.B1 (NO_2)
unnamed: J5.P1 (DAT2), R3.2
unnamed: J5.P8 (DAT1), R26.2
unnamed: Q1.1 (B), R1.1
unnamed: Q2.1 (B), R2.1
RADIO_BUSY: MOD1.5 (SENSOR_VN); also elsewhere on the board
RADIO_DIO1: MOD1.6 (IO34); also elsewhere on the board
RADIO_DIO2: MOD1.7 (IO35); also elsewhere on the board
RADIO_NRST: MOD1.24 (IO2); also elsewhere on the board
RADIO_NSS: MOD1.29 (IO5); also elsewhere on the board
RADIO_RXEN: MOD1.10 (IO25); also elsewhere on the board
RADIO_TXEN: MOD1.11 (IO26); also elsewhere on the board
RGB_LED_B: MOD1.14 (IO12); also elsewhere on the board
SDCARD_NSS: J5.P2 (CD/DAT3), MOD1.13 (IO14), R13.1
VSPI_MISO: J5.P7 (DAT0), MOD1.31 (IO19), R5.2; also elsewhere on the board
VSPI_MOSI: J5.P3 (CMD), MOD1.37 (IO23); also elsewhere on the board
VSPI_SCLK: J5.P5 (CLK), MOD1.30 (IO18); also elsewhere on the board

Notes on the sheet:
Serial 0
Pin 12 (GPS_ON_OFF) may need to have a pull-up or a pull-down ressitor depending on the ESP internal flash. Note that the pull-down resistors are in the "Tecommunications" page on the gate of the Mosfet that actuates the GPS. This is needed because pin 12 is a bootstrap pin, used to select the inte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
Read about the pull-up resitors for SD cards here: https://electronics.stackex change.com/questions/39 571/how-to-do-pulling-up -or-down-correctly-when- interfacing-a-microsd-card
Auto Program Upload DTR RTS --> EN IO0 1 1 1 1 0 0 1 1 1 0 0 1 0 1 1 0
Reset Button
ESP32 Flash Voltage Pin
ESP32
Auto Upload
External Picoblade
SD Card
If there is any trouble reading pins, check the internal pull resistors, they vary with every pin.
Serial 2
Boot Button
Power
Telecommunications
Peripherals

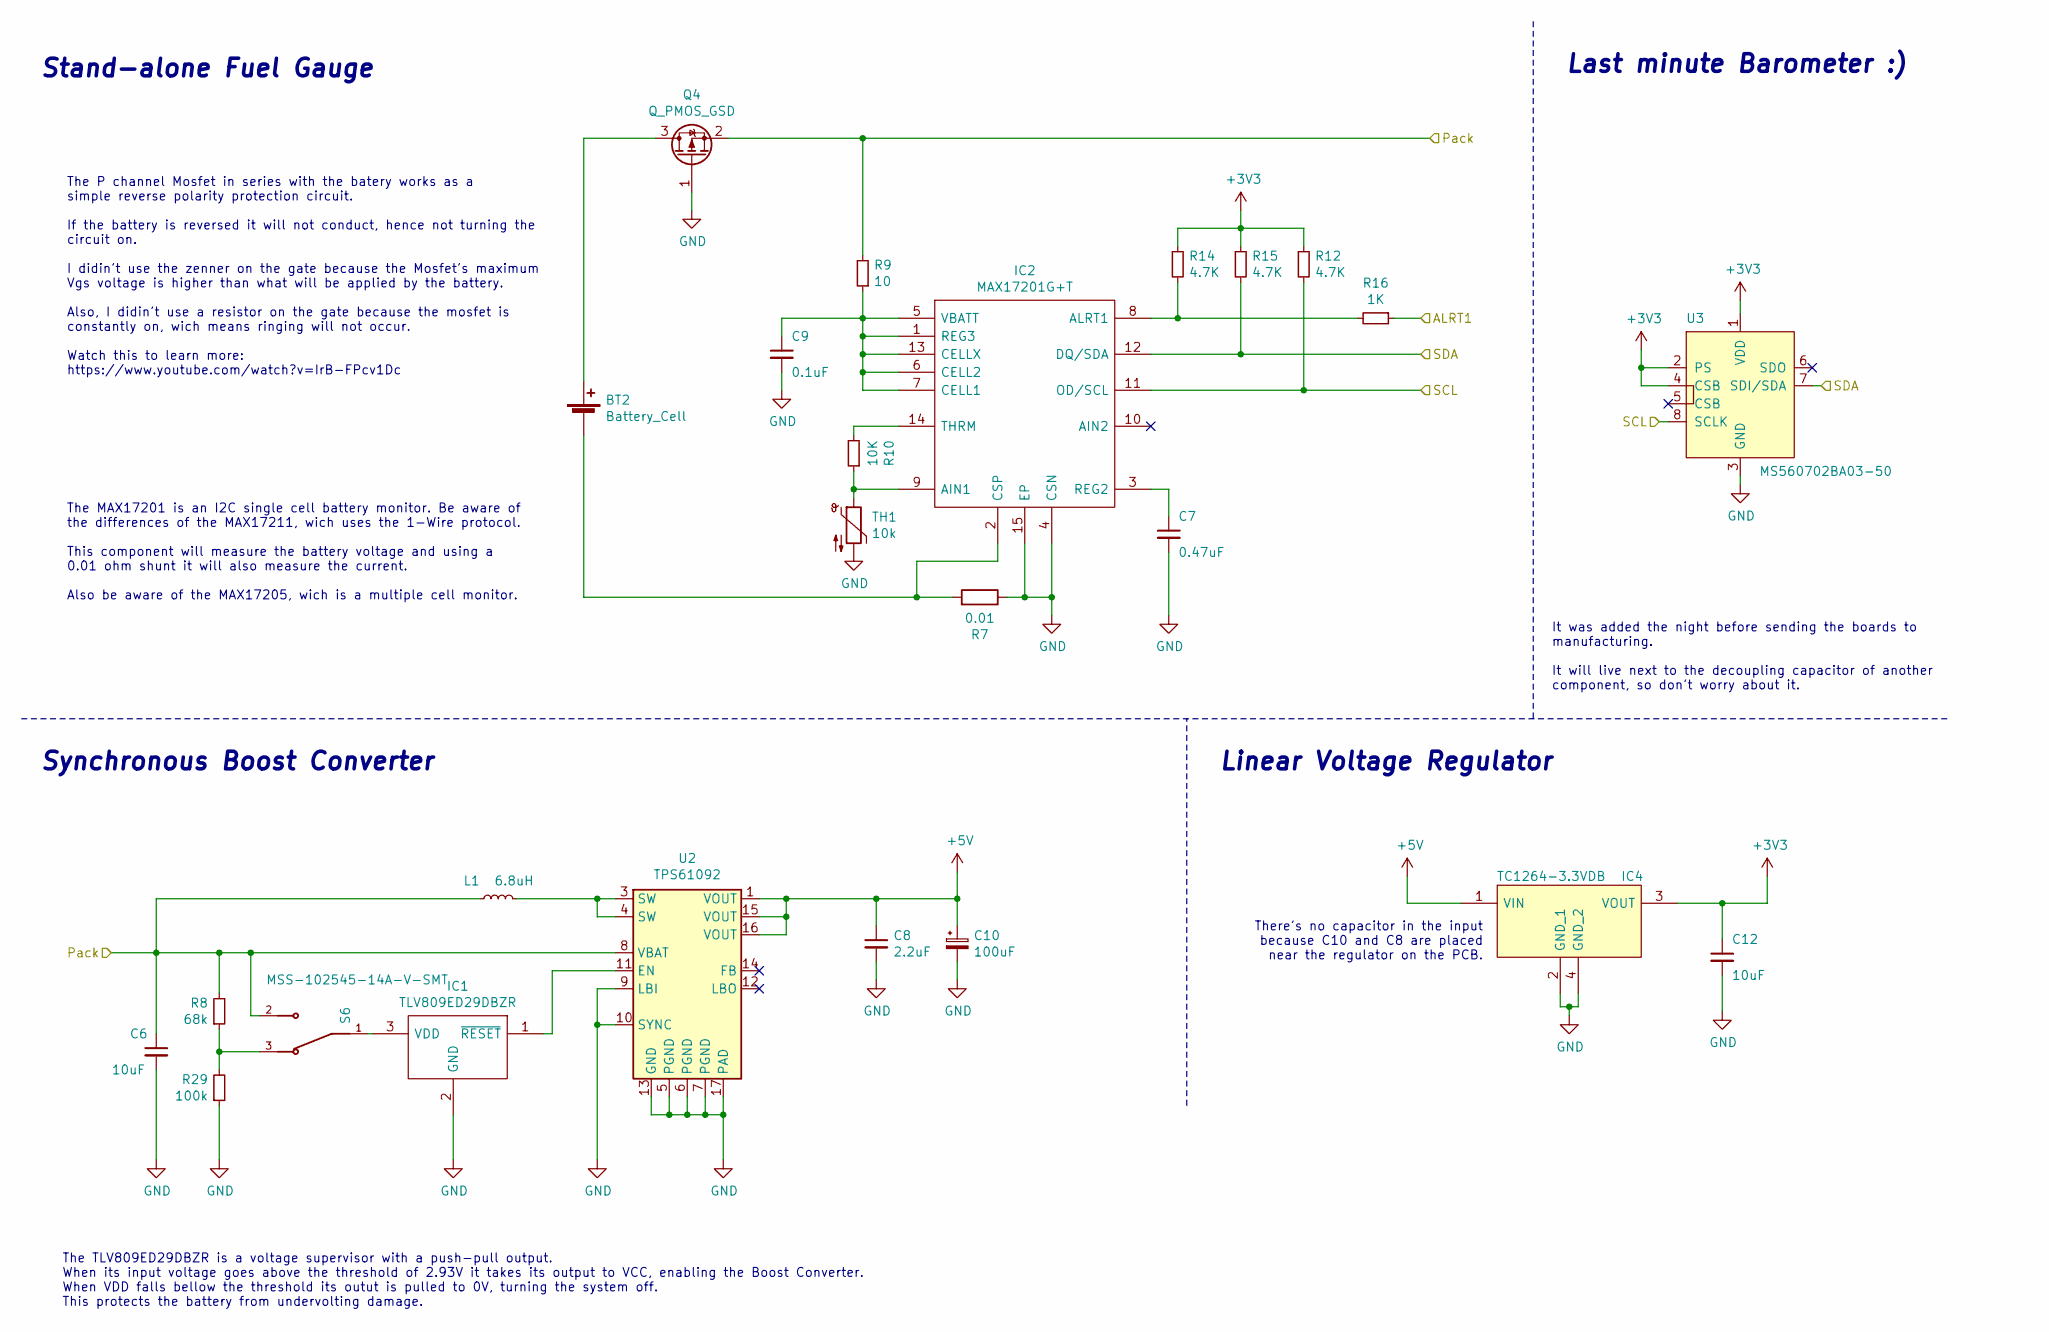
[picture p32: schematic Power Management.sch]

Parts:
BT2: Battery_Cell; BatteryHolder_Keystone_1042_1x18650_Modified
C6, C12: 10uF; C_1206_3216Metric
C7: 0.47uF; C_0603_1608Metric
C8: 2.2uF; C_1206_3216Metric
C9: 0.1uF; C_0603_1608Metric
C10: 100uF; CP_Elec_5x5.3
IC1: TLV809ED29DBZR; SOT95P237X112-3N; Mouser Part Number 595-TLV809ED29DBZR
IC2: MAX17201G+T; SON40P300X300X80-15N; Mouser Part Number 700-MAX17201G+T
IC4: TC1264-3.3VDB; SOT230P700X180-4N; Mouser Part Number 579-TC1264-3.3VDB
L1: 6.8uH; INDPM4040X210N
Q4: Q_PMOS_GSD; SOT346
R7: 0.01; R_0805_2012Metric
R8: 68k; R_0603_1608Metric
R9: 10; R_0603_1608Metric
R10: 10K; R_0603_1608Metric
R12, R14, R15: 4.7K; R_0603_1608Metric
R16: 1K; R_0603_1608Metric
R29: 100k; R_0603_1608Metric
S6: MSS-102545-14A-V-SMT; SW_MSS-102545-14A-V-SMT; PARTREV 1.0
TH1: 10k; R_0402_1005Metric
U2: TPS61092; Texas_S-PVQFN-N16_EP2.7x2.7mm_ThermalVias
U3: MS560702BA03-50; SMD-8_5x3mm; MPN MS560702BA03-50; Digi-Key_PN 223-1198-1-ND

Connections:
+3V3: C12.1, IC4.3 (VOUT), R12.1, R14.1, R15.1, U3.1 (VDD), U3.2 (PS), U3.4 (CSB); also elsewhere on the board
+5V: C8.1, C10.1, IC4.1 (VIN), U2.1 (VOUT), U2.15 (VOUT), U2.16 (VOUT); also elsewhere on the board
/Power Management/Pack: C6.1, L1.2, Q4.2 (S), R8.2, R9.2, S6.2, U2.8 (VBAT)
GAUGE_ALRT1: R16.1; also elsewhere on the board
GAUGE_SCL: IC2.11 (OD/SCL), R12.2, U3.8 (SCLK); also elsewhere on the board
GAUGE_SDA: IC2.12 (DQ/SDA), R15.2, U3.7 (SDI/SDA); also elsewhere on the board
GND: C6.2, C7.2, C8.2, C9.2, C10.2, C12.2, IC1.2 (GND), IC2.4 (CSN), IC2.15 (EP), IC4.2 (GND_1), IC4.4 (GND_2), Q4.1 (G), R7.1, R29.1, TH1.2, U2.5 (PGND), U2.6 (PGND), U2.7 (PGND), U2.9 (LBI), U2.10 (SYNC), U2.13 (GND), U2.17 (PAD), U3.3 (GND); also elsewhere on the board
unnamed: BT2.1 (+), Q4.3 (D)
unnamed: BT2.2 (-), IC2.2 (CSP), R7.2
unnamed: C7.1, IC2.3 (REG2)
unnamed: C9.1, IC2.1 (REG3), IC2.5 (VBATT), IC2.6 (CELL2), IC2.7 (CELL1), IC2.13 (CELLX), R9.1
unnamed: IC1.1 (~RESET), U2.11 (EN)
unnamed: IC1.3 (VDD), S6.1
unnamed: IC2.8 (ALRT1), R14.2, R16.2
unnamed: IC2.9 (AIN1), R10.1, TH1.1
unnamed: IC2.14 (THRM), R10.2
unnamed: L1.1, U2.3 (SW), U2.4 (SW)
unnamed: R8.1, R29.2, S6.3

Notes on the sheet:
Linear Voltage Regulator
Synchronous Boost Converter
Stand-alone Fuel Gauge
The TLV809ED29DBZR is a voltage supervisor with a push-pull output. When its input voltage goes above the threshold of 2.93V it takes its output to VCC, enabling the Boost Converter. When VDD falls bellow the threshold its outut is pulled to 0V, turning the system off. This protects the battery fro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
The P channel Mosfet in series with the batery works as a simple reverse polarity protection circuit. If the battery is reversed it will not conduct, hence not turning the circuit on. I didin't use the zenner on the gate because the Mosfet's maximum Vgs voltage is higher than what will be applied b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
The MAX17201 is an I2C single cell battery monitor. Be aware of the differences of the MAX17211, wich uses the 1-Wire protocol. This component will measure the battery voltage and using a 0.01 ohm shunt it will also measure the current. Also be aware of the MAX17205, wich is a multiple cell monitor.
There's no capacitor in the input because C10 and C8 are placed near the regulator on the PCB.
Last minute Barometer :)
It was added the night before sending the boards to manufacturing. It will live next to the decoupling capacitor of another component, so don't worry about it.

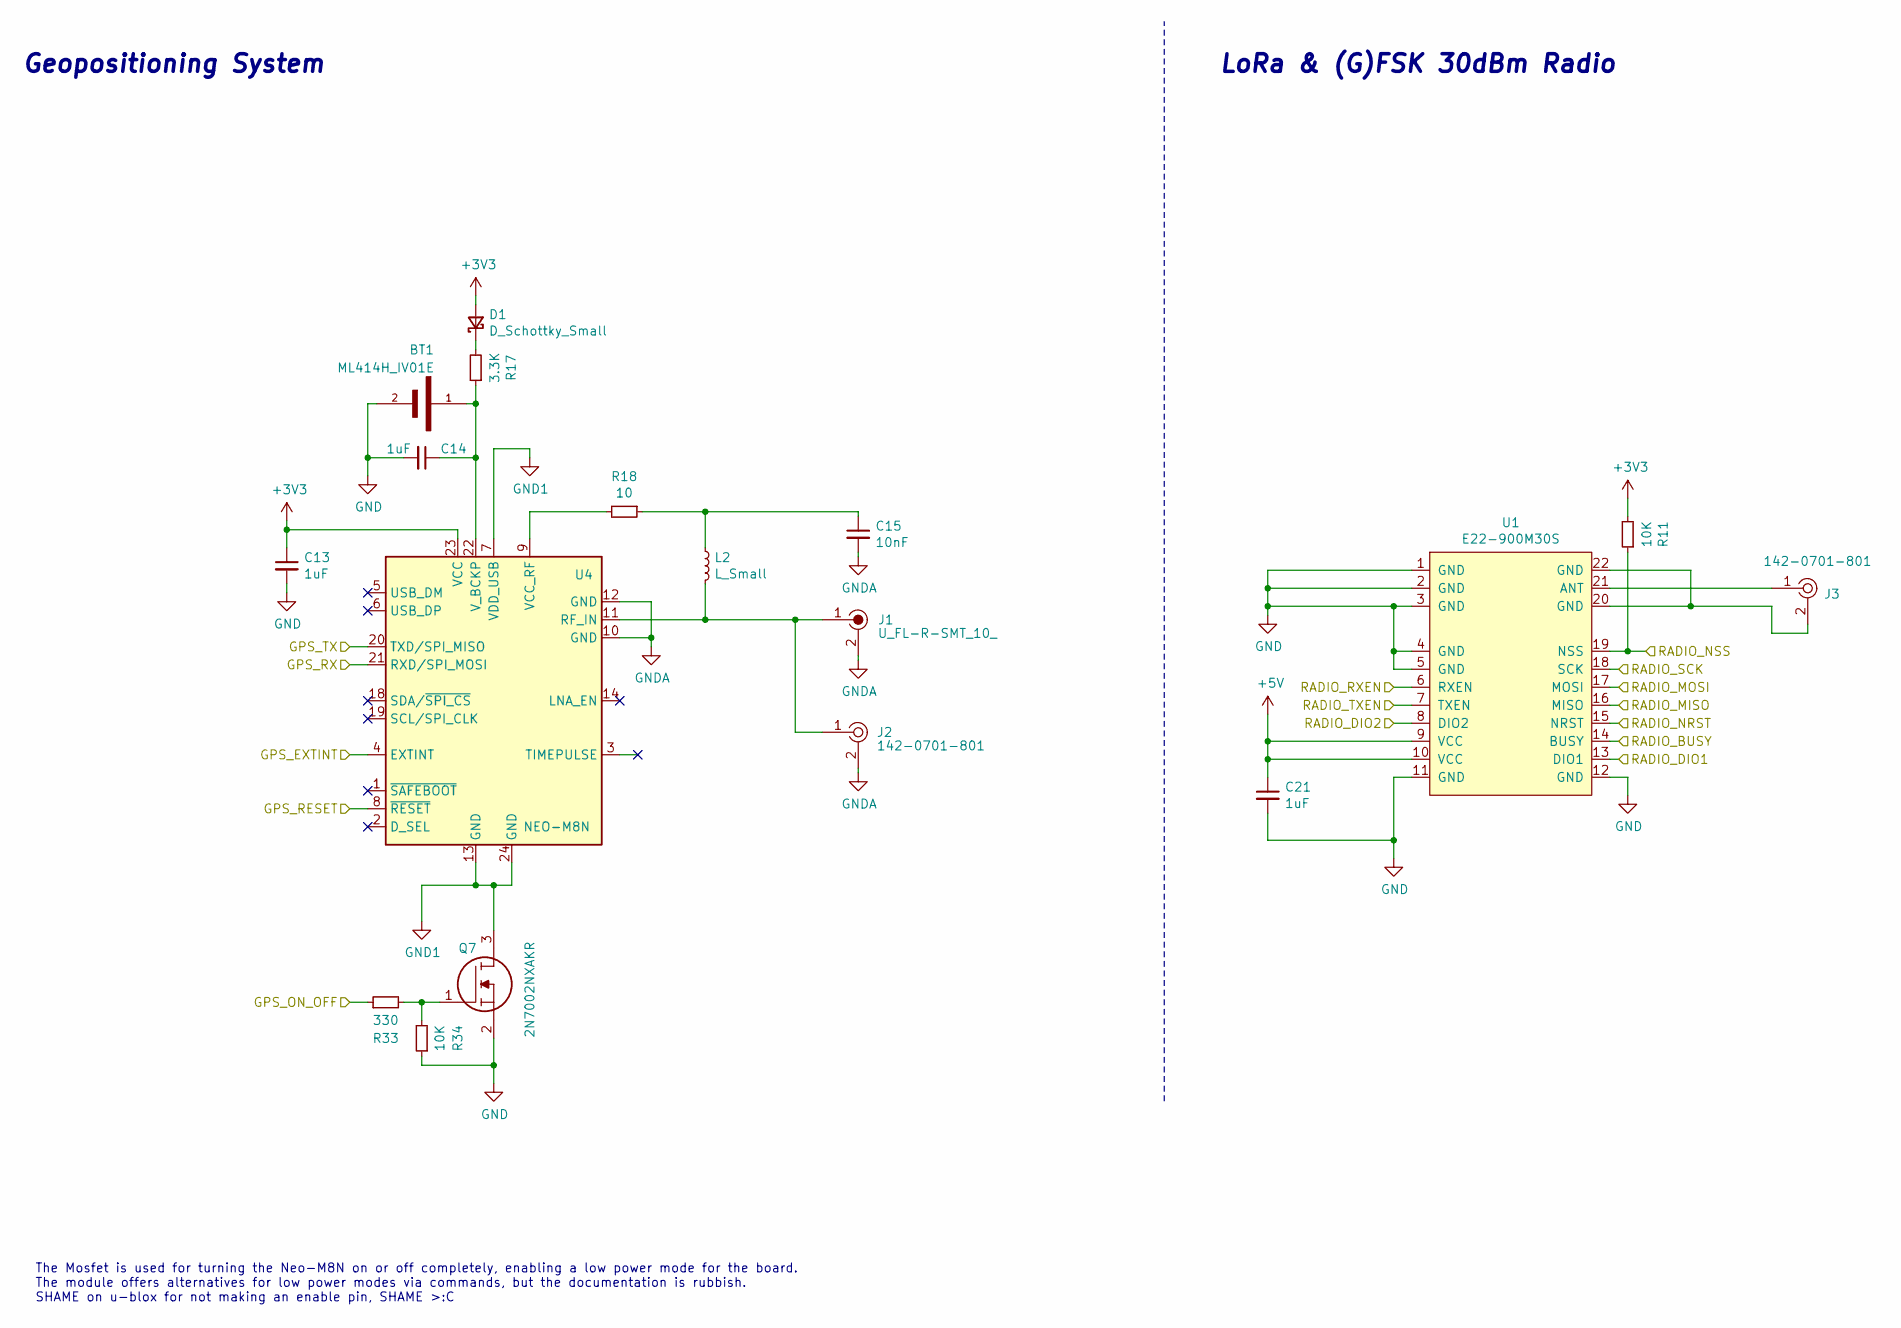
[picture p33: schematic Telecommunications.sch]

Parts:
BT1: ML414H_IV01E; SEIKO_ML414H_IV01E
C13, C14: 1uF; C_0603_1608Metric
C15: 10nF; C_0603_1608Metric
C21: 1uF; C_1206_3216Metric
D1: D_Schottky_Small; D_0603_1608Metric
J1: U_FL-R-SMT_10_; U.FL_Hirose_U.FL-R-SMT-1_Vertical; MPN U.FL-R-SMT(10); Digi-Key_PN H9161CT-ND
J2, J3: 142-0701-801; SMA_Amphenol_132289_EdgeMount; MPN 142-0701-801; Digi-Key_PN J502-ND
L2: L_Small; L_0402_1005Metric_Pad0.77x0.64mm_HandSolder
Q7: 2N7002NXAKR; SOT95P230X110-3N; Mouser Part Number 771-2N7002NXAKR
R11, R34: 10K; R_0603_1608Metric
R17: 3.3K; R_0603_1608Metric
R18: 10; R_0603_1608Metric
R33: 330; R_0603_1608Metric
U1: E22-900M30S
U4: NEO-M8N; ublox_NEO

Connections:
+3V3: C13.1, D1.2 (A), R11.2, U4.23 (VCC); also elsewhere on the board
+5V: C21.1, U1.9 (VCC), U1.10 (VCC); also elsewhere on the board
GND: BT1.2, C13.2, C14.2, C21.2, Q7.2, R34.1, U1.1 (GND), U1.2 (GND), U1.3 (GND), U1.4 (GND), U1.5 (GND), U1.11 (GND), U1.12 (GND); also elsewhere on the board
GND1: Q7.3, U4.7 (VDD_USB), U4.13 (GND), U4.24 (GND)
GNDA: C15.2, J1.2, J2.2, U4.10 (GND), U4.12 (GND)
GPS_EXTINT: U4.4 (EXTINT); also elsewhere on the board
GPS_ON_OFF: R33.1; also elsewhere on the board
GPS_RESET: U4.8 (~RESET); also elsewhere on the board
GPS_RX: U4.21 (RXD/SPI_MOSI); also elsewhere on the board
GPS_TX: U4.20 (TXD/SPI_MISO); also elsewhere on the board
unnamed: BT1.1, C14.1, R17.1, U4.22 (V_BCKP)
unnamed: C15.1, L2.1, R18.1
unnamed: D1.1 (K), R17.2
unnamed: J1.1, J2.1, L2.2, U4.11 (RF_IN)
unnamed: J3.1, U1.21 (ANT)
unnamed: J3.2, U1.20 (GND), U1.22 (GND)
unnamed: Q7.1, R33.2, R34.2
unnamed: R18.2, U4.9 (VCC_RF)
RADIO_BUSY: U1.14 (BUSY); also elsewhere on the board
RADIO_DIO1: U1.13 (DIO1); also elsewhere on the board
RADIO_DIO2: U1.8 (DIO2); also elsewhere on the board
RADIO_NRST: U1.15 (NRST); also elsewhere on the board
RADIO_NSS: R11.1, U1.19 (NSS); also elsewhere on the board
RADIO_RXEN: U1.6 (RXEN); also elsewhere on the board
RADIO_TXEN: U1.7 (TXEN); also elsewhere on the board
VSPI_MISO: U1.16 (MISO); also elsewhere on the board
VSPI_MOSI: U1.17 (MOSI); also elsewhere on the board
VSPI_SCLK: U1.18 (SCK); also elsewhere on the board

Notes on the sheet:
Geopositioning System
LoRa & (G)FSK 30dBm Radio
The Mosfet is used for turning the Neo-M8N on or off completely, enabling a low power mode for the board. The module offers alternatives for low power modes via commands, but the documentation is rubbish. SHAME on u-blox for not making an enable pin, SHAME >:C

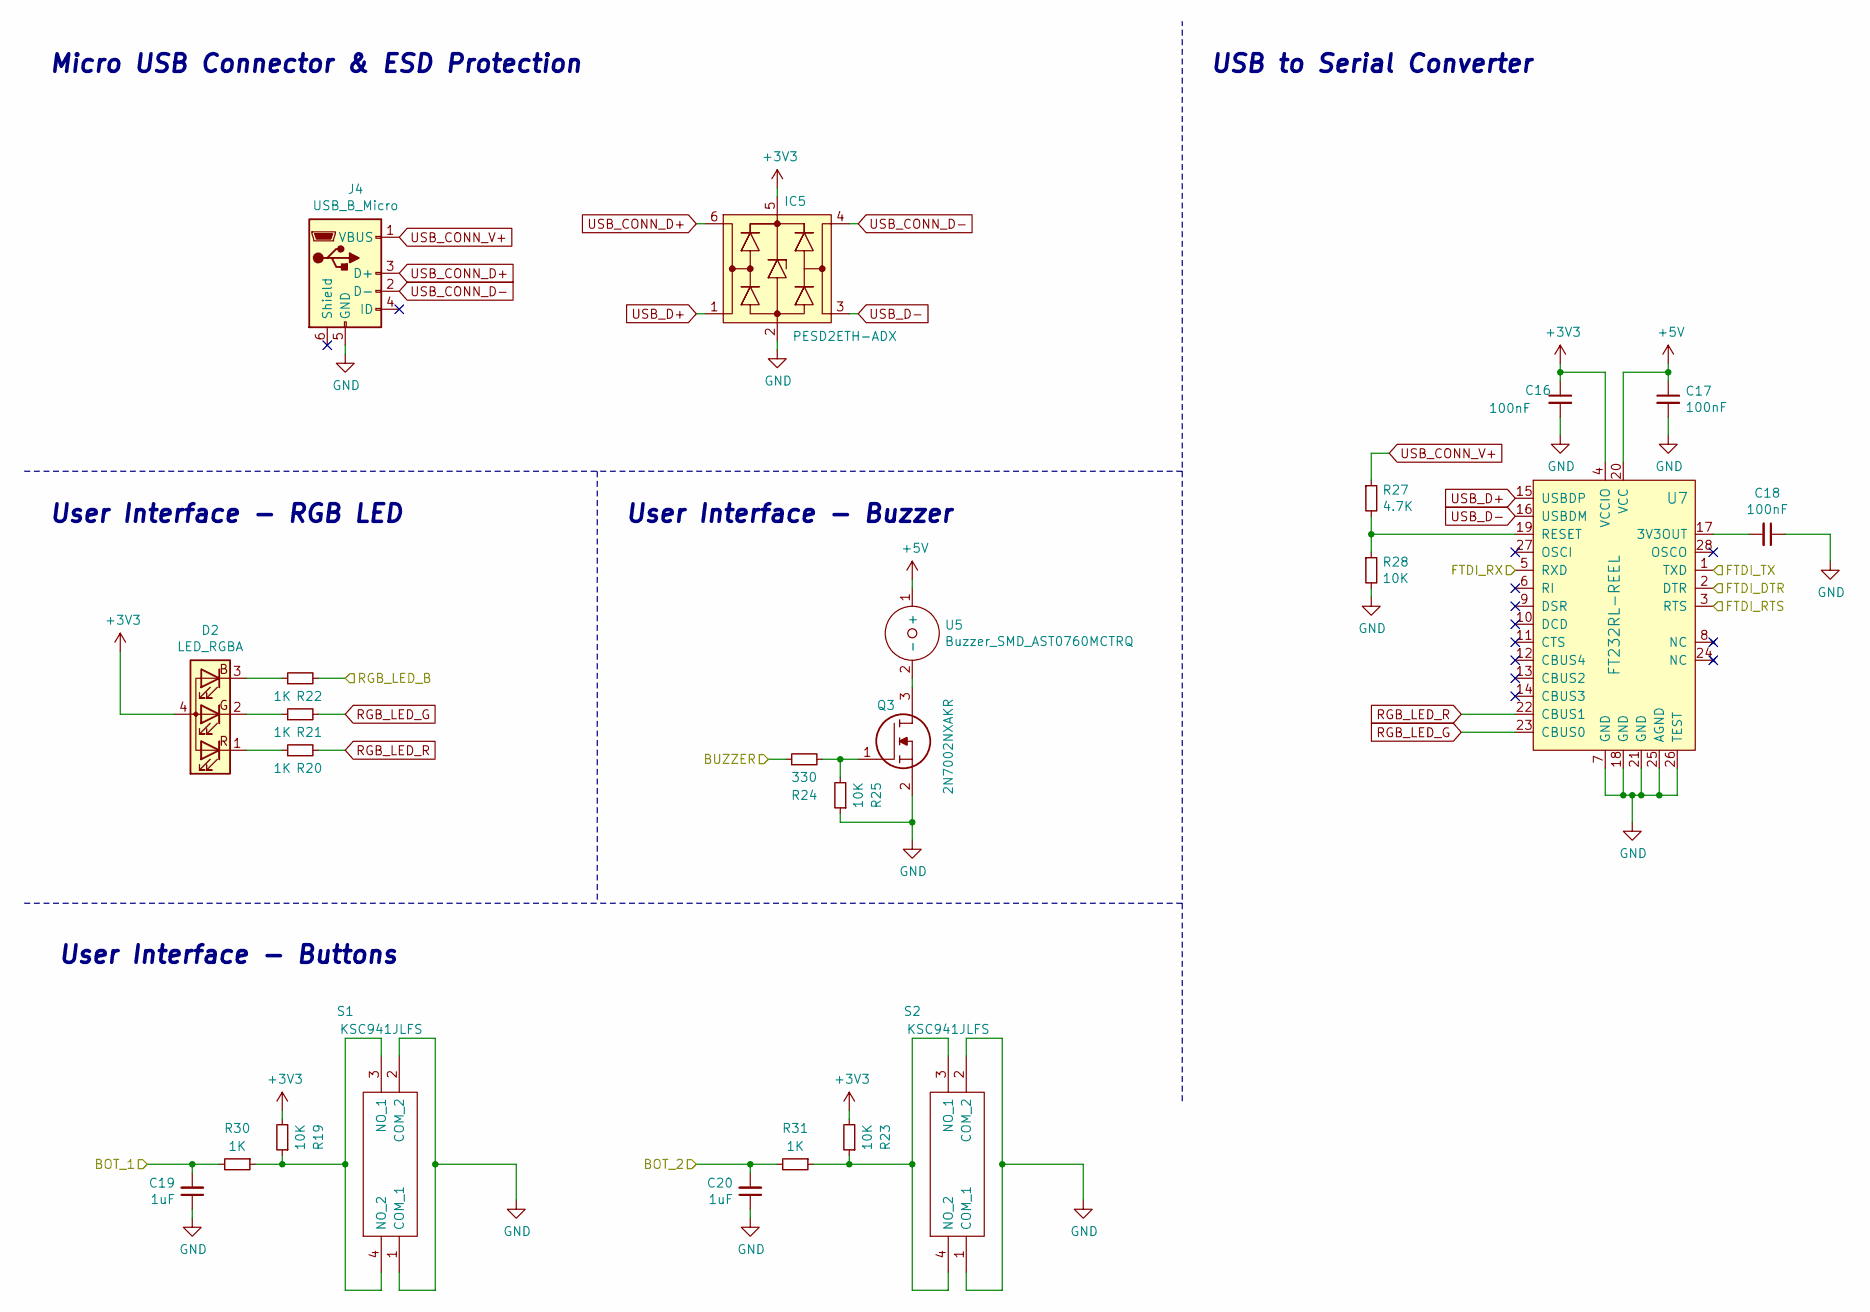
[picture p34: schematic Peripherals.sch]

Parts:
C16, C17, C18: 100nF; C_0603_1608Metric
C19, C20: 1uF; C_0603_1608Metric
D2: LED_RGBA; LED_D5.0mm-4_RGB_Wide_Pins
IC5: PESD2ETH-ADX; SOT95P275X110-6N; Mouser Part Number 771-PESD2ETH-ADX
J4: USB_B_Micro; USB_Micro_B_Female_10118192
Q3: 2N7002NXAKR; SOT95P230X110-3N; Mouser Part Number 771-2N7002NXAKR
R19, R23, R25, R28: 10K; R_0603_1608Metric
R20, R21, R22, R30, R31: 1K; R_0603_1608Metric
R24: 330; R_0603_1608Metric
R27: 4.7K; R_0603_1608Metric
S1, S2: KSC941JLFS; Mouser Part Number 611-KSC941JLFS
U5: Buzzer_SMD_AST0760MCTRQ; AST0760MCTRQ
U7: FT232RL-REEL; SSOP-28_W5.30mm; MPN FT232RL-REEL; Digi-Key_PN 768-1007-1-ND

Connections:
+3V3: C16.1, D2.4 (A), IC5.5, R19.2, R23.2, U7.4 (VCCIO); also elsewhere on the board
+5V: C17.1, U5.1 (+), U7.20 (VCC); also elsewhere on the board
BUTTON_1: C19.2, R30.2; also elsewhere on the board
BUTTON_2: C20.2, R31.2; also elsewhere on the board
BUZZER: R24.1; also elsewhere on the board
FTDI_DTR: U7.2 (DTR); also elsewhere on the board
FTDI_RTS: U7.3 (RTS); also elsewhere on the board
FTDI_RX: U7.5 (RXD); also elsewhere on the board
FTDI_TX: U7.1 (TXD); also elsewhere on the board
GND: C16.2, C17.2, C18.1, C19.1, C20.1, IC5.2, J4.5 (GND), Q3.2, R25.1, R28.2, S1.1 (COM_1), S1.2 (COM_2), S2.1 (COM_1), S2.2 (COM_2), U7.7 (GND), U7.18 (GND), U7.21 (GND), U7.25 (AGND), U7.26 (TEST); also elsewhere on the board
unnamed: C18.2, U7.17 (3V3OUT)
unnamed: D2.1 (RK), R20.1
unnamed: D2.2 (GK), R21.1
unnamed: D2.3 (BK), R22.1
unnamed: Q3.1, R24.2, R25.2
unnamed: Q3.3, U5.2 (-)
unnamed: R19.1, R30.1, S1.3 (NO_1), S1.4 (NO_2)
unnamed: R23.1, R31.1, S2.3 (NO_1), S2.4 (NO_2)
unnamed: R27.2, R28.1, U7.19 (RESET)
RGB_LED_B: R22.2; also elsewhere on the board
RGB_LED_G: R21.2, U7.23 (CBUS0)
RGB_LED_R: R20.2, U7.22 (CBUS1)
USB_CONN_D+: IC5.6, J4.3 (D+)
USB_CONN_D-: IC5.4, J4.2 (D-)
USB_CONN_V+: J4.1 (VBUS), R27.1
USB_D+: IC5.1, U7.15 (USBDP)
USB_D-: IC5.3, U7.16 (USBDM)

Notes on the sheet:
Micro USB Connector & ESD Protection
USB to Serial Converter
User Interface - Buttons
User Interface - RGB LED
User Interface - Buzzer

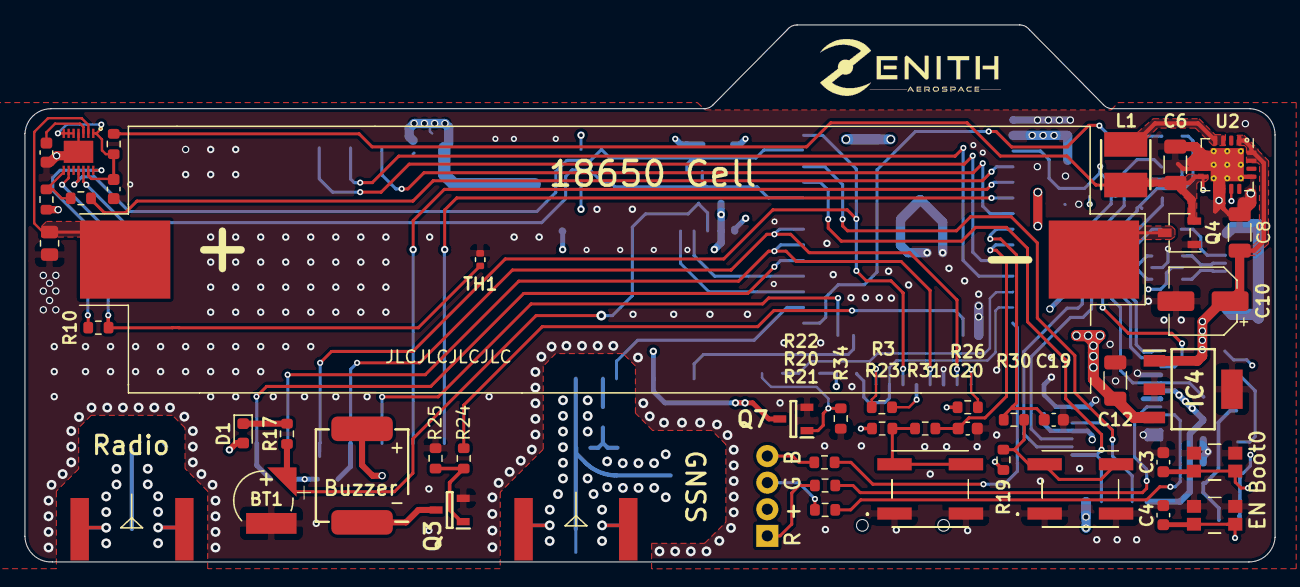
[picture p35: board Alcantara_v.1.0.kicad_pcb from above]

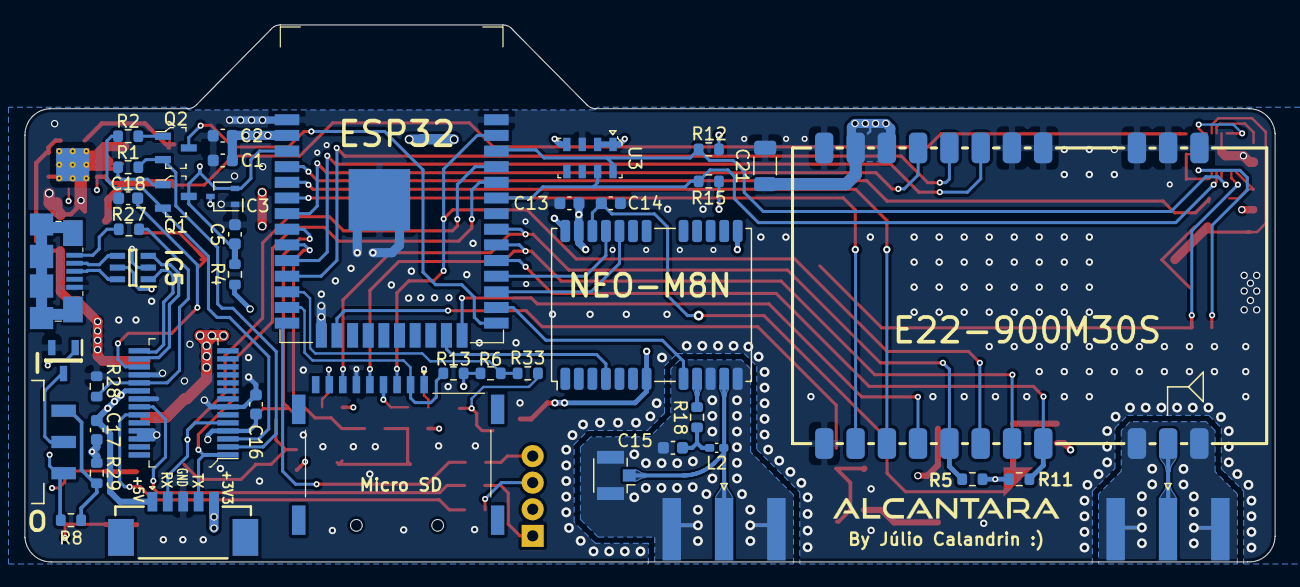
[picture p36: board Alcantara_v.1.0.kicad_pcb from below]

Board: 4 copper layers, 101.5 x 43.6 mm, 88 parts (43 on the bottom side), 74 nets.

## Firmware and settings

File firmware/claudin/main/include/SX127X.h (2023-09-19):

/*
   SX127X.c
   Author: Júlio Calandrin
   Made with care, hate and sweat by someone that doesn't really knows what it's doing.
*/

#include "claudin-spi.h"
#include "driver/gpio.h"
#include "freertos/task.h"

// TODO: Fight the urge to use goto for error handling

/*
 * ERROR HANDLING
 */
#define RETURN_ON_ERROR(status);\
		if(status != ESP_OK){\
			return status;\
	        }

/*
 * Mutual register addresses
 */
#define SX127X_REG_FIFO             			(uint8_t)0x00
#define SX127X_REG_OP_MODE          			(uint8_t)0x01
#define SX127X_REG_FRF_MSB				(uint8_t)0x06	// RF carrier Frequency MSB
#define SX127X_REG_FRF_MID				(uint8_t)0x07	// RF carrier Frequency MID
#define SX127X_REG_FRF_LSB				(uint8_t)0x08	// RF carrier Frequency LSB
#define SX127X_REG_PA_CONFIG				(uint8_t)0x09	// Power Amplifier Configuration
#define SX127X_REG_PA_RAMP				(uint8_t)0x0A	// Power Amplifier ramp up/down time
#define SX127X_REG_OCP		   			(uint8_t)0x0B	// Over Current Protection Configuration
#define SX127X_REG_LNA	 				(uint8_t)0x0C	// Low-Noise Amplifier Configuration
#define SX127X_REG_DIO_MAPPING_1			(uint8_t)0x40
#define SX127X_REG_DIO_MAPPING_2			(uint8_t)0x41
#define SX127X_REG_VERSION				(uint8_t)0x42	// Semtech ID relating the silicon revision
#define SX127X_REG_TCXO					(uint8_t)0x4B	// TCXO or XTAL input setting
#define SX127X_REG_PA_DAC           			(uint8_t)0x4D 	// High power settings of the Power Amplifier
#define SX127X_REG_FORMER_TEMP				(uint8_t)0x5B	// Stored temperature during the former IQ Calibration
#define SX127X_REG_AGC_REF				(uint8_t)0x61	// Adjustment of the AGC thresholds
#define SX127X_REG_AGC_THRESH1				(uint8_t)0x62	// Adjustment of the AGC thresholds
#define SX127X_REG_AGC_THRESH2				(uint8_t)0x63	// Adjustment of the AGC thresholds
#define SX127X_REG_AGC_THRESH3				(uint8_t)0x64	// Adjustment of the AGC thresholds
#define SX127X_REG_PLL					(uint8_t)0x70	// Control of the PLL bandwidth


/*
 * LoRa register addresses
 */

#define LORA_REG_FIFO_ADDR_PTR				0x0D	// SPI Interface FIFO Pointer
#define LORA_REG_FIFO_TX_BASE_ADDR			0x0E	// Base address for TX writing on FIFO
#define LORA_REG_FIFO_RX_BASE_ADDR			0x0F	// Base address for RX reading on FIFO
#define LORA_REG_FIFO_RX_CURRENT_ADDR			0x10	// Address of last packet received
#define LORA_REG_IRQ_FLAGS_MASK				0x11	// Interrupt Request Flags Mask
#define LORA_REG_IRQ_FLAGS				0x12	// Interrupt Request Flags
#define LORA_REG_RX_NB_BYTES				0x13	// Number of received bytes
#define LORA_REG_RX_HEADER_CNT_MSB			0x14	// Number of valid headers received since last transition into Rx mode MSB
#define LORA_REG_RX_HEADER_CNT_LSB			0x15	// Number of valid headers received since last transition into Rx mode LSB
#define LORA_REG_RX_PACKET_CNT_MSB			0x16	// Number of valid packets received since last transition into Rx mode MSB
#define LORA_REG_RX_PACKET_CNT_LSB			0x17	// Number of valid packets received since last transition into Rx mode LSB
#define LORA_REG_MODEM_STAT				0x18	// Modem status
#define LORA_REG_PKT_SNR_VALUE				0x19	// Last Packet Signal-to-Noise Ratio
#define LORA_REG_PKT_RSSI_VALUE				0x1A	// Last Packet Received Signal Strength Indicator
#define LORA_REG_RSSI_VALUE				0x1B	// Current Received Signal Strength Indicator
#define LORA_REG_HOP_CHANNEL				0x1C	// FHSS start channel
#define LORA_REG_MODEM_CONFIG_1				0x1D	// Modem Configuration 1
#define LORA_REG_MODEM_CONFIG_2				0x1E	// Modem Configuration 2
#define LORA_REG_SYMB_TIMEOUT_LSB			0x1F	// Receiver timeout LSB. MSBs are in Modem Config
#define LORA_REG_PREAMBLE_MSB				0x20	// Preamble size MSB
#define LORA_REG_PREAMBLE_LSB				0x21	// Preamble size MSB
#define LORA_REG_PAYLOAD_LENGTH				0x22	// Payload Lenght
#define LORA_REG_MAX_PAYLOAD_LENGTH			0x23	// Maximum Payload Lenght
#define LORA_REG_HOP_PERIOD				0x24	// FHSS HOP Period
#define LORA_REG_FIFO_RX_BYTE_ADDR			0x25	// Address of last byte written in FIFO
#define LORA_REG_MODEM_CONFIG_3				0x26	// Modem Configuration 3
#define LORA_REG_FREQ_ERROR_MSB				0x28	// Estimated frequency error MSB
#define LORA_REG_FREQ_ERROR_MID				0x29	// Estimated frequency error MID
#define LORA_REG_FREQ_ERROR_LSB				0x2A	// Estimated frequency error LSB
#define LORA_REG_RSSI_WIDEBAND				0x2C	// Wideband RSSI measurement
#define LORA_REG_LF_FREQ_1				0x2F	// Optimize receiver
#define LORA_REG_LF_FREQ_2				0x30	// Optimize receiver
#define LORA_REG_DETECTION_OPTIMIZE			0x31	// Detection Optimize for Spreading Factor 6
#define LORA_REG_INVERTIQ				0x33	// Invert LoRa I and Q signals
#define LORA_REG_HIGH_BW_OPTIMIZE1			0x36	// Sensitivity optimization for 500 kHz bandwidth
#define LORA_REG_DETECTION_THRESHOLD			0x37	// Detection Threshold for Spreading Factor 6
#define LORA_REG_SYNC_WORD				0x39	// Sync Word
#define LORA_REG_HIGH_BW_OPTIMIZE2			0x3A	// Sensitivity optimization for 500 kHz bandwidth
#define LORA_REG_INVERTIQ2				0x3B	// Optimize for inverted IQ

/* LoRa Operation Modes (section 4.1.3) */
#define LoRa_LOW_FREQ_MODE				0x08
#define LoRa_get_MODE(reg_val)				(reg_val&0b10000111)
#define LoRa_MODE_SLEEP					0x80
#define LoRa_MODE_STANDBY				0x81
#define LoRa_MODE_FSTX					0x82
#define LoRa_MODE_TX					0x83
#define LoRa_MODE_FSRX					0x84
#define LoRa_MODE_RX_CONT				0x85
#define LoRa_MODE_RX_SINGLE				0x86
#define LoRa_MODE_CAD					0x87

/* LoRa Cyclic Redundancy Check (CRC) */
#define LoRa_CRC_SET(reg_val)				(reg_val|0x04)
#define LoRa_CRC_RESET(reg_val)				(reg_val&0xFB)

/* LoRa Low Data Rate Optimize */
#define LoRa_LDO_SET(reg_val)				(reg_val|0b00001000)
#define LoRa_LDO_RESET(reg_val)				(reg_val&0b11110111)

/* LoRa Spreading Factor (section 4.1.1.2) */
#define LoRa_set_SF(reg_val, sf)			((reg_val&0x0F)|((sf<<4)&0xF0))

/* LoRa Power Amplifier (section 5.4.1 and 5.4.2)*/
#define LoRa_PA_RFO_PIN					0x70
#define LoRa_PA_BOOST_PIN				0x80

/* LoRa Over Current Protection (section 5.4.4) */
#define LoRa_OCP_SET(ocp_trim)				(0x20|(0x1F & ocp_trim))
#define LoRa_OCP_RESET					0x00

/* LoRa Coding Rate (section 4.1.1.3) */
#define LoRa_set_CR(reg_val, cr)			((reg_val&0xF1)|cr)
#define LoRa_CR_4_5					0x02
#define LoRa_CR_4_6					0x04
#define LoRa_CR_4_7					0x06
#define LoRa_CR_4_8					0x08

/* LoRa Header Modes (section 4.1.1.6) */
#define LoRa_EXPLICIT(reg_val)				(reg_val & 0b11111110)
#define LoRa_IMPLICIT(reg_val)				(reg_val | 0b00000001)

/* LoRa DIO LoRa Mapping (section 4.1.6.1) */
#define LoRa_RXDONE					0x00
#define LoRa_TXDONE					0x40

/* LoRa Idle config (section 4.2.8.2) */
#define LoRa_REG_SEQ_CONFIG_1				0x36

/* Macros */
#define LoRa_IGNORE_RESET_PIN				0xFFFF	// Use this in init to ignore reset pin
#define LoRa_TIMEOUT					100

/*
 * FSK register addresses
 */

#define FSK_REG_BITRATE_MSB		   		(uint8_t)0x02
#define FSK_REG_BITRATE_LSB     	  		(uint8_t)0x03
#define FSK_REG_FDEV_MSB				(uint8_t)0x04
#define FSK_REG_FDEV_LSB				(uint8_t)0x05
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

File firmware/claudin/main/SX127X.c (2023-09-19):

#include "SX127X.h"

esp_err_t FSK_init(SX127X_t *SX127X) {
  esp_err_t status = ESP_OK;

  // didnt configure anything, all DEFAULT.
  status = SX127X_Reset(SX127X);
  RETURN_ON_ERROR(status);

  return ESP_OK;
}

esp_err_t SX127X_Config(SX127X_t *SX127X) {
  esp_err_t status = ESP_OK;

  // Universal Configs:

  status = SX127X_Reset(SX127X);
  RETURN_ON_ERROR(status);

  status = SX127X_set_op_mode(SX127X, SLEEP);
  RETURN_ON_ERROR(status);

  status = SX127X_set_modulation(SX127X, SX127X->Current_Modulation);
  RETURN_ON_ERROR(status);

  status = SX127X_set_frequency(SX127X, SX127X->Frequency);
  RETURN_ON_ERROR(status);

  status = FSK_set_pa_ramp_time(SX127X, SX127X->PaRampTime);
  RETURN_ON_ERROR(status);

  status = SX127X_set_lna_gain(SX127X, SX127X->LnaGain);
  RETURN_ON_ERROR(status);

  status = SX127X_set_lna_boost(SX127X, SX127X->LnaBoost);
  RETURN_ON_ERROR(status);

  status = SX127X_set_pa_output(SX127X, SX127X->PaSelect);
  RETURN_ON_ERROR(status);

  status = SX127X_set_tx_power(SX127X, SX127X->TxPower);
  RETURN_ON_ERROR(status);

  if (SX127X->Current_Modulation == FSK_Modulation) {

    status = FSK_set_freq_deviation(
        SX127X, SX127X->FSK_Config.FrequencyDeviation,
        SX127X->FSK_Config.Bitrate); // Bitrate.BitrateValue
    RETURN_ON_ERROR(status);

    status = FSK_set_bitrate(
        SX127X, SX127X->FSK_Config.Bitrate); // Bitrate.RegisterValue
    RETURN_ON_ERROR(status);

    status = FSK_set_preamb_len(SX127X, SX127X->FSK_Config.PreambleLength,
                                SX127X->FSK_Config.PreamblePolarity);
    RETURN_ON_ERROR(status);

    if (SX127X->FSK_Config.SyncWordGeneration == true) {
      status = FSK_set_sync_word(SX127X, SX127X->FSK_Config.SyncWordSize,
                                 SX127X->FSK_Config.SyncWord);
      RETURN_ON_ERROR(status);
    } else {
      status = FSK_disable_sync_word(SX127X);
      RETURN_ON_ERROR(status);
    }

    status = FSK_set_packet_format(SX127X, SX127X->FSK_Config.PacketFormat);
    RETURN_ON_ERROR(status);

    status = FSK_set_data_processing_mode(
        SX127X, SX127X->FSK_Config.DataProcessingMode);
    RETURN_ON_ERROR(status);

    status = FSK_set_payload_length(SX127X, SX127X->FSK_Config.PayloadLength);
    RETURN_ON_ERROR(status);

    if (SX127X->FSK_Config.CrcCalculation == true) {
      status = FSK_enable_crc(SX127X);
      RETURN_ON_ERROR(status);
      status = FSK_set_crc_whitenning_type(
          SX127X, SX127X->FSK_Config.CrcWhitenningType);
      RETURN_ON_ERROR(status);
      status = FSK_set_crc_autoclear(SX127X, SX127X->FSK_Config.CrcAutoclear);
      RETURN_ON_ERROR(status);

    } else {
      status = FSK_disable_crc(SX127X);
      RETURN_ON_ERROR(status);
    }

    status = FSK_set_encoding(SX127X, SX127X->FSK_Config.Encoding);
    RETURN_ON_ERROR(status);

    status = FSK_set_data_shaping(SX127X, SX127X->FSK_Config.DataShaping);
    RETURN_ON_ERROR(status);

    status = FSK_set_auto_restart_RX(SX127X, SX127X->FSK_Config.AutoRestartRX);
    RETURN_ON_ERROR(status);

    // RX config:

    status = FSK_set_rx_bandwidth(SX127X, SX127X->FSK_Config.RxBandwidth);
    RETURN_ON_ERROR(status);

    status = FSK_set_afc_bandwidth(SX127X, SX127X->FSK_Config.AfcBandwidth);
    RETURN_ON_ERROR(status);

    if (SX127X->FSK_Config.PreambleDetectorOn == true) {
      status = FSK_enable_preamble_detector(
          SX127X, SX127X->FSK_Config.PreambleDetectorSize,
          SX127X->FSK_Config.PreambleDetectorTolerance);
      RETURN_ON_ERROR(status);
    } else {
      status = FSK_disable_preamble_detector(SX127X);
      RETURN_ON_ERROR(status);
    }

    /*
      status = FSK_set_auto_restart_rx(SX127X,
      SX127X->FSK_Config.AutoRestartRX); RETURN_ON_ERROR(status);

      status = FSK_set_restart_rx_on_collision(SX127X,
      SX127X->FSK_Config.RestartRxOnCollision); RETURN_ON_ERROR(status);
    */

    /*
      if(SX127X->FSK_Config.AddressFiltering != NoFiltering){
        status = FSK_set_address_filter(SX127X, SX127X->FSK_Config.NodeAdress,
      SX127X->FSK_Config.BroadcastAddress); RETURN_ON_ERROR(status); }else{
        status = FSK_disable_address_filter(SX127X);
        RETURN_ON_ERROR(status);
      }
    */

    status = FSK_set_rssi_offset(SX127X, SX127X->FSK_Config.RssiOffset);
    RETURN_ON_ERROR(status);

    status = FSK_set_rssi_smoothing(SX127X, SX127X->FSK_Config.RssiSmoothing);
    RETURN_ON_ERROR(status);

    // DIO config: (perhaps joining them in a single function that gets which
    // DIO pin we are talking about may be useful) For that we would need to
    // make all dio functions fit in a  single enum for a single data type

    // For now, I'm reusing the function from the last version:
    status = SX127X_set_DIO_mapping(SX127X, SX127X->DioMapping1,
                                    SX127X->DioMapping2);
    RETURN_ON_ERROR(status);

    /*
      status = FSK_set_dio0_function(SX127X, SX127X->FSK_Config.DIO0Function);
      RETURN_ON_ERROR(status);

      status = FSK_set_dio1_function(SX127X, SX127X->FSK_Config.DIO1Function);
      RETURN_ON_ERROR(status);

      status = FSK_set_dio2_function(SX127X, SX127X->FSK_Config.DIO2Function);
      RETURN_ON_ERROR(status);

      status = FSK_set_dio3_function(SX127X, SX127X->FSK_Config.DIO3Function);
      RETURN_ON_ERROR(status);

      status = FSK_set_dio4_function(SX127X, SX127X->FSK_Config.DIO4Function);
      RETURN_ON_ERROR(status);

      status = FSK_set_dio5_function(SX127X, SX127X->FSK_Config.DIO5Function);
      RETURN_ON_ERROR(status);
    */
  }

  status = SX127X_set_op_mode(SX127X, STANDBY);
  RETURN_ON_ERROR(status);

  return status;
}

esp_err_t SX127X_Reset(SX127X_t *SX127X) {
  esp_err_t status = ESP_OK;

  // HAL_GPIO_WritePin(SX127X->reset_gpio_port, SX127X->reset_pin,
  // GPIO_PIN_RESET);
  gpio_set_level(SX127X->ss_pin, 0);
  vTaskDelay(30 / portTICK_PERIOD_MS);

  // HAL_GPIO_WritePin(SX127X->reset_gpio_port, SX127X->reset_pin,
  // GPIO_PIN_SET);
  gpio_set_level(SX127X->ss_pin, 1);
  vTaskDelay(30 / portTICK_PERIOD_MS);
  return status;
}
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

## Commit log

2021-09-02 Updated silk screens and components 3D models
    [Alcantara_v.1.0 .kicad_pcb, Alcantara_v.1.0.kicad_pcb, Alcantara_v.1.0.sch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]
2022-01-16 Updated RF section ground planes.
    [Alcantara_v.1.0.kicad_pcb, Alcantara_v.1.0.sch, Power Management.sch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]
2022-01-16 Deleting excess files
    [Alcantara_v.1.0.csv]
2022-01-16 Origanized Folders
    [Alcantara_v.1.0.kicad_pcb, Alcantara_v.1.0.sch, GPS - NEO-M8N.sch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]
2022-01-17 Added Images
    [Alcantara_v.1.0.kicad_pcb, Alcantara_v.1.0.sch, Peripherals.sch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]
2022-01-17 Renamed Files
    [Alcantara_v.1.0.kicad_pcb, Alcantara_v.1.0.sch, GPS - NEO-M8N.sch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]
2022-01-20 Add shapes 3D folder
    Now all 3D models for the components are stored in a single folder, thanks to the Archive Plugin from https://github.com/MitjaNemec/Kicad_action_plugins.git
    [2N7002NXAKR.stp, AST0760MCTRQ.step, Alcantara_v.1.0.sch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]
2022-01-20 Update PCB 3D shape file paths
    [Alcantara_v.1.0.kicad_pcb]
2022-02-20 Realocated and replaced components
    Components where replaced because of the chip shortage, such as the 3.3 V Voltage regulator, the USB ESD protector and the SD Card holder.
    The ESP32 has been rotated and moved closer to the center of the board, now having it's antenna positioned outside of the original board outline, providing better range for the Bluetooth and Wi-Fi.
    [Alcantara_v.1.0.kicad_pcb, Alcantara_v.1.0.sch, Peripherals.sch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]
2022-02-23 Reduces board length to 101,5 mm
    JLC PCB allows a 4 layer PCB to be manufactured for just $8,00 if it is within 102 x 102 mm. The previous version was 105,47 mm, making it cost $37,00.
    To reduce the manufacturing cost the board had its size cut down to 101,5 mm. This was possible by moving the buzzer from the top left corner of the board to the free space between the two SMA connectors.
    [Alcantara_v.1.0-B_Cu.gbl, Alcantara_v.1.0-B_Mask.gbs, Alcantara_v.1.0-B_Paste.gbp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]
2022-02-23 Update README.md
    Update board renders
2022-02-23 Archive 3D Models
    [Alcantara_v.1.0.kicad_pcb]
2022-06-09 Change radio's decoupling capacitor to the 1206 packaging size.
    Upgrades the radios capacitor and rerouted it's traces to better accommodate grounding vias.
    [Alcantara_v.1.0.kicad_pcb, Telecommunications.sch]
2022-07-14 Add MS5607 barometer.
    Adds MS5607 barometer and reorganized silkscreen.
    [Alcantara_v.1.0.kicad_pcb, Power Management.sch]
2023-09-19 added claudin files
    [2N7002NXAKR.stp, AST0760MCTRQ.step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]

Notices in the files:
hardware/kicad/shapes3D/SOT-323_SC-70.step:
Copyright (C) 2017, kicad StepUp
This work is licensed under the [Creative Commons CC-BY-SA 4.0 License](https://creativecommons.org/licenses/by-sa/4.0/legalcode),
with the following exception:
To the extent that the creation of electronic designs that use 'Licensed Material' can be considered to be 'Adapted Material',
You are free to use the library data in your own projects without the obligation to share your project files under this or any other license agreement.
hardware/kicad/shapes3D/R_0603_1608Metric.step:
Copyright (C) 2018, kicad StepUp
